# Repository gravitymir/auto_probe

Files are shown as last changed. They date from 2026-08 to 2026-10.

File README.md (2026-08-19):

# auto_probe

Отладочные core-платы на STM32 — исходники KiCad, гербера и генератор, который их собирает.

Платы не рисовались мышкой: схема, размещение, разводка и шелкография описаны Python-скриптами
поверх `pcbnew` API. Любую правку можно повторить одной командой, а результат каждый раз
прогоняется через набор проверок.

## Платы

| | STM32G474RE-CoreBoard | STM32H723ZG-CoreBoard |
|---|---|---|
| МК | STM32G474RET6, LQFP64 | STM32H723ZGT6, LQFP144 |
| Размер | 70 × 70 мм | 84 × 84 мм |
| Слоёв | 4 (GND / +3V3 внутренние) | 4 (GND / +3V3 внутренние) |
| Выводы | 4 × гребёнка 1×16, шаг 2.54 | 4 × гребёнка 2×18, шаг 2.54 |
| Питание | USB-C → AP2112K-3.3 | USB-C → AP2112K-3.3 |
| Кварцы | 8 МГц HSE + 32.768 кГц LSE | 25 МГц HSE + 32.768 кГц LSE |
| Отладка | 1×10, распиновка WeAct STLink V2.1 | 1×10, распиновка WeAct STLink V2.1 |
| Формат файлов | KiCad 7 | KiCad 10 |
| Статус | **готова к заказу** | **готова к заказу** |

Все выводы микроконтроллера выведены на гребёнки; шаг 2.54 мм — плата садится в макетку.
У H723 внутренние ряды гребёнок отстоят от центра ровно на 11 × 2.54 мм, то есть
противоположные гребёнки разнесены на 22 шага и плата ложится на сетку 0.1″.

## Что на плате (G474)

**Гребёнки.** J2 — левая, J3 — нижняя, J4 — правая, J5 — верхняя. Назначение каждого
контакта подписано на шелкографии и продублировано в [`PINOUT.csv`](boards/STM32G474RE-CoreBoard/PINOUT.csv).
На каждой гребёнке выведены GND и +3V3 — они подключены к внутренним полигонам через
thermal relief, отдельных дорожек к ним нет.

**J6 — разъём прошивки**, 1×10, распиновка один-в-один с WeAct MiniDebugger / STLink V2.1,
шлейф садится без переходников:

| 1 | 2 | 3 | 4 | 5 | 6 | 7 | 8 | 9 | 10 |
|---|---|---|---|---|---|---|---|---|---|
| 5V | GND | RX (PB6) | TX (PB7) | NRST | SWO (PB3) | GND | SWCLK | SWDIO | 3V3 |

> Контакт 1 (5V) связан с VBUS разъёма USB-C. **USB и отладчик одновременно не подключайте.**

**USB-C (J1)** — не только питание: D+/D− заведены на PA12/PA11, то есть на встроенный
USB 2.0 FS device. Через него работают USB CDC (виртуальный COM-порт) и штатный DFU-бутлоадер
STM32 — прошивка без отладчика вообще. CC1/CC2 притянуты 5.1 кОм к земле (роль устройства).

**Кнопки.** SW1 — RST, SW2 — BOOT0 (для входа в DFU: зажать BOOT, нажать RST).

**Светодиод.** D1 на PA5 (`LED_A`), через 1 кОм.

**R3 (0 Ω)** связывает +3V3 и +3V3A (VDDA / VREF+) в одной точке. Если АЦП будет шуметь —
на это же место ставится ферритовая бусина, переразводить ничего не нужно.

## Чем отличается H723

Раскладка повторяет G474: кристалл смещён к нижнему левому углу (`OFFX` / `OFFY` в
генераторе), поэтому верхнее и правое кольца шире — там и стоят светодиод, кнопки RST и
BOOT, разъём прошивки, USB-C и брендинг. USB-C стоит на плате целиком: корпус упирается
в контур, но за него не свисает.

Электрически устроена так же: те же гребёнки со всеми выводами, тот же USB-C с D+/D− на
встроенный USB FS (PA11/PA12), те же кнопки RST и BOOT0, светодиод (здесь на PB0 через
1 кОм), тот же R3 между +3V3 и +3V3A. Разъём прошивки J6 — тот же 1×10 с распиновкой
WeAct, но UART другой:

| 1 | 2 | 3 | 4 | 5 | 6 | 7 | 8 | 9 | 10 |
|---|---|---|---|---|---|---|---|---|---|
| 5V | GND | RX (PC10) | TX (PC11) | NRST | SWO (PB3) | GND | SWCLK | SWDIO | 3V3 |

Взят USART3 на PC10/PC11, а не USART1: у LQFP144 эта пара выходит на верхнюю гребёнку
рядом со SWCLK, тогда как PA9/PA10 попадают на правую гребёнку за коридором USB-C, куда
дорожку уже не проложить. Ещё из отличий: 25 МГц HSE вместо 8 МГц, две банки VCAP1/VCAP2
по 2.2 мкФ, отдельная развязка VDD33USB и 11 конденсаторов развязки под корпусом вместо 4.

HSE стоит в корпусе SMD-3225 с четырьмя падами: у JLCPCB 25 МГц в нём — Basic Part
(Yangxing X322525MOB4SI, `C9006`), тогда как двухпадовый 5032 только Extended и с
перебоями в наличии. Два лишних пада — экран корпуса, они связаны диагональю под
самим кварцем и посажены на полигон одной via. Нагрузочная ёмкость этого кварца
12 пФ, поэтому обвязка обоих генераторов — 18 пФ; кварц с другой CL ставить нельзя,
частота уйдёт.

Подписан каждый из 144 контактов, оба ряда. У J2, J3 и J5 ряды подписаны с разных сторон
гребёнки — внутренний изнутри, внешний снаружи. Напротив USB-C правое кольцо занято самим
разъёмом и его коридором, поэтому у J4 обе строки остаются слева. Подпись, которой не
хватило места, генератор сам переносит за гребёнку и сообщает об этом в отчёте сборки.
Полная карта — в [`PINOUT.csv`](boards/STM32H723ZG-CoreBoard/PINOUT.csv).

Шрифт шелкографии — 0.8 мм при толщине линии 0.15 мм: это минимум, который JLCPCB
печатает без расплывания. В кольце между гребёнкой и краем платы остаётся 3.7 мм, и
пятизначное имя таким шрифтом туда уже не входит — у нескольких цепей на шелке
короткая форма (`3V3A`, `PC2C`, `USBDP`). В цепях, схеме и `PINOUT.csv` имена полные.

Рядом с деталью печатается только обозначение: под корпусом МК банки развязки стоят
сеткой 3.2 мм, и номиналы читаемым шрифтом там просто не помещаются. Вместо этого на
обратной стороне, в свободных площадках у J4, напечатана таблица «обозначение —
номинал» на все 35 компонентов платы.

Схема H723 нарисована на листе A1: один символ LQFP144 занимает 76 × 188 мм, и вместе с
четырьмя гребёнками 2×18 и 26 конденсаторами на A2 (как у G474) он не раскладывается.

## Как открыть

Футпринты у обеих плат лежат в собственной библиотеке проекта `auto_probe.pretty` рядом с
платой и подключаются через `fp-lib-table` — системные библиотеки KiCad не нужны, и проект
не зависит от того, какая версия KiCad стоит у вас или у сборщика.

```
boards/STM32G474RE-CoreBoard/STM32G474RE-CoreBoard.kicad_pro
boards/STM32H723ZG-CoreBoard/STM32H723ZG-CoreBoard.kicad_pro
```

G474 сохранена в формате KiCad 7 (KiCad 8/9/10 открывают её и конвертируют при первом
сохранении), H723 — в формате KiCad 10: её собирали уже им. Платы независимы, так что
разные форматы никому не мешают, но KiCad 7 файл H723 не откроет.

## Как заказать

Для JLCPCB / PCBWay достаточно одного архива:

```
boards/STM32G474RE-CoreBoard/STM32G474RE-CoreBoard_gerbers.zip
boards/STM32H723ZG-CoreBoard/STM32H723ZG-CoreBoard_gerbers.zip
```

Внутри: 4 слоя меди, паяльная маска, шелкография, паста, контур платы (`.gm1`) и сверловка
(PTH / NPTH раздельно). Параметры заказа: 4 слоя, 1.6 мм, HASL или ENIG, минимальный
зазор 0.2 мм, минимальное отверстие 0.2 мм.

Для монтажа на заводе — `BOM.csv` и `pos.csv` рядом с платой. В BOM G474 проставлены
номера LCSC для микроконтроллера, стабилизатора и USB-C; у H723 — для стабилизатора и
USB-C, номер самого STM32H723ZGT6 подставьте сами. Пассивку подберите из JLCPCB Basic
Parts по номиналу и типоразмеру.

## Генератор

```
gen/
├── kigen.py        разбор библиотек символов, генерация .kicad_sch
├── pcbhelp.py      обёртка над pcbnew: размещение, дорожки, via, полигоны, текст
├── kicadenv.py     где лежат библиотеки KiCad и различия API между версиями
├── build_g474.py   сборка платы G474 целиком
├── build_h723.py   сборка платы H723
├── outputs.py      BOM.csv и PINOUT.csv из готовой платы
├── export.py       гербера, сверловка, pos.csv, PDF и архив для завода
├── drc.py          геометрический контроль зазоров + несоединённые цепи
├── conn.py         связность цепей (union-find)
├── crtyd.py        пересечения courtyard
└── silkchk.py      наложения шелкографии и печать поверх падов
```

Нужен Python с модулем `pcbnew` — от KiCad 7 или KiCad 10 (в Debian/Ubuntu — пакет
`kicad`, в Windows — `C:\Program Files\KiCad\10.0\bin\python.exe`). Каталоги системных
библиотек скрипты находят сами:

```bash
python3 gen/build_h723.py boards/STM32H723ZG-CoreBoard
python3 gen/outputs.py    boards/STM32H723ZG-CoreBoard/STM32H723ZG-CoreBoard.kicad_pcb
python3 gen/export.py     boards/STM32H723ZG-CoreBoard
python3 gen/drc.py        boards/STM32H723ZG-CoreBoard/STM32H723ZG-CoreBoard.kicad_pcb
python3 gen/silkchk.py    boards/STM32H723ZG-CoreBoard/STM32H723ZG-CoreBoard.kicad_pcb
```

`export.py` зовёт `kicad-cli`; им же гоняется штатный DRC:

```bash
kicad-cli pcb drc --schematic-parity --severity-error boards/STM32H723ZG-CoreBoard/STM32H723ZG-CoreBoard.kicad_pcb
```

Позиции надписей, выставленные вручную в KiCad, хранятся в `build_g474.py` в таблицах
`REF_AT` и `VAL_AT` — пересборка их не затирает. Остальные надписи расставляет автоподбор,
который считает занятыми чужие надписи, контуры, **пады** (шелк поверх открытой меди не
печатается) и **корпуса деталей** (иначе надпись уезжает под чип и её не видно).

## Проверки

У KiCad 7 в CLI нет DRC, поэтому проверки написаны отдельно. Текущее состояние обеих плат:

| проверка | G474 | H723 |
|---|---|---|
| зазоры меди | 0 нарушений при штатных 0.2 мм | 0 нарушений при штатных 0.2 мм |
| DRC самого KiCad | 0 ошибок | 0 ошибок |
| схема против платы | — | 0 расхождений |
| несоединённые цепи | 0 | 0 |
| пересечения courtyard | 0 | 0 |
| отверстие-отверстие | минимум 0.387 мм | минимум 0.278 мм |
| наложения шелкографии | 0 | 0 |
| шелкография поверх падов | 0 | 0 |

Обе платы проходят штатный DRC самого KiCad (проверено в KiCad 10) — 0 ошибок при netclass
clearance 0.2 мм. Сигнальные дорожки 0.15 мм, силовые 0.35 мм; минимум JLCPCB для этого
процесса — 0.09 мм. У H723 есть ещё и проверка схемы против платы (`--schematic-parity`),
её умеет только CLI KiCad 10.

Веер из 144 выводов на четыре гребёнки 2×18 упирается не в ширину дорожки, а в угол:
крайние дорожки идут под 42°, и поперёк соседа от шага 0.5 мм остаётся 0.5·cos42° = 0.37 мм.
Отсюда и вынос гребёнок на 27.94 мм от центра — на 26 мм веер в зазор 0.2 мм не укладывался
ни при какой разумной ширине.

## Что осталось

- На D+/D− нет защиты от статики (например, USBLC6-2SC6) — для прототипа терпимо.
- D+/D− заодно выведены на J4 контакты 3 и 4. Удобно для отладки, но это отвод на
  дифференциальной паре: если USB начнёт капризничать при определении — снимите с них всё.
- VBUS не заведён на вывод МК, определить подключение кабеля программно нельзя.

## Лицензия

MIT — см. [LICENSE](LICENSE).

Референсные материалы ST (схемы Nucleo MB1367 / MB1364, их гербера и BOM) в репозиторий
не включены: они распространяются по ST Open Platform License Agreement. Разбор того, что
из них полезно и как это открыть в KiCad, — в [docs/](docs/).

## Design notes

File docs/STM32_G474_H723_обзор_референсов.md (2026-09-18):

# Прототипы отладочных плат STM32G474RET6 (LQFP64) и STM32H723ZGT6 (LQFP144)

Обзор готовых открытых проектов + план собственных плат.
Дата: 16 августа 2026.

---

## 1. Короткий вывод

**Готового open-source «core board» ровно под ваши корпуса — нет.**

- Под **G474 в LQFP64** открытых KiCad-исходников не существует; все народные платы сделаны на **LQFP48/QFN48** (G474CEU6/CBT6).
- Под **H723 в LQFP144** народных плат тоже нет; WeAct сделал **LQFP100** (H723VGT6). LQFP144 встречается только в коммерческих платах (FANKE FK723M1) и в чужих больших проектах.

Зато есть два очень сильных «якоря», которые снимают 80 % работы:

1. **Официальные файлы ST на Nucleo** — там ровно ваши кристаллы в ровно ваших корпусах, и ST выкладывает не только схему PDF, но и **исходный проект платы (Altium) + производственные файлы (гербера) + BOM**.
2. **KiCad уже содержит символы и футпринты** `STM32G474RETx`, `STM32H723ZGTx`, `LQFP-64_10x10mm_P0.5mm`, `LQFP-144_20x20mm_P0.5mm` — рисовать компоненты не надо (проверено на KiCad 7, в 8/9 то же самое).

---

## 2. Что нашлось: STM32G474

| Проект | Корпус / MCU | Что отдают | Лицензия | Ценность |
|---|---|---|---|---|
| **ST NUCLEO-G474RE (MB1367)** | **LQFP64, G474RET6** — точное попадание | Схема PDF (ревизии C04/C05/D01), `mb1367_bdp.zip` — **исходный проект платы**, `mb1367_manufacturing.zip` — **гербера**, `mb1367_bom.zip` | ST (для референса) | ★★★★★ Эталон питания, кварцев, BOOT0, NRST, SWD |
| **ST B-G474E-DPOW1 (MB1428)** | LQFP64, G474RE | Схема + UM2577 + BDP | ST | ★★★★ Второй независимый референс обвязки |
| **nikolai2111/STM32G474_Black-Pill_v3.0** | UFQFPN48, G474CEU6 | **Полный исходник KiCad 8** (.kicad_sch/.kicad_pcb), гербера, панель, BOM (xlsx+pdf), 3D, PCB-Fab | **CERN-OHL-P-2.0** (разрешительная, можно брать в закрытый проект) | ★★★★★ Единственный полноценный KiCad-исходник. Готовая обвязка: USB-C, LDO AP7343, BAT54, QSPI-флеш W25Q32, кнопки BOOT/RESET |
| **WeActStudio.STM32G474CoreBoard** | QFN48 и LQFP48 | Только схема PDF + STEP + чертёж контура | не указана | ★★★ Ориентир по формфактору «квадратный core board» |

**Что берём:** схемотехнику обвязки — из Black Pill v3.0 (готовые KiCad-цепи, копируются мышкой); распиновку/питание LQFP64 — из MB1367.

---

## 3. Что нашлось: STM32H723

| Проект | Корпус / MCU | Что отдают | Лицензия | Ценность |
|---|---|---|---|---|
| **ST NUCLEO-H723ZG (MB1364)** | **LQFP144, H723ZGT6** — точное попадание | Схема PDF, `mb1364_bdp.zip` (**исходник платы**), `mb1364_manufacturing.zip` (**гербера**), `mb1364-bom.zip` | ST | ★★★★★ Эталон: развязка 11×VDD, VCAP, VDD33USB, PDR_ON, стек слоёв |
| **FANKE FK723M1-ZGT6** | **LQFP144, H723ZGT6** | Схема PDF; поддержан «из коробки» в Zephyr | коммерческая | ★★★★ Это буквально ваш формфактор: 2 × гребёнка 30×2 + SWD 4×2, USB-C, QSPI-флеш, microSD, FPC под LCD/камеру. Дешевле купить как reference, чем повторять |
| **WeActStudio.MiniSTM32H723** | LQFP100, H723VGT6 | Схема PDF, STEP, Altium IntLib, чертёж контура 40.64 × 66.88 мм | не указана | ★★★ Хороший минимальный H7 core board, но не 144 |
| **BoltzRnD/SmartPrintCoreH7x** | LQFP144 (H743ZIT, в BOM альтернатива H723ZGT) | **Полный KiCad-проект** + гербера + BOM | **GPL-3.0** ⚠️ вирусная | ★★★ Живой KiCad-пример LQFP144 STM32H7. Смотреть можно, копировать в закрытый проект — нельзя |

⚠️ H743ZIT и H723ZGT в LQFP144 **пин-совместимы по питанию и большинству портов**, но не идентичны — сверять по даташиту обязательно.

---

## 4. Ключевые факты по обвязке (проверено по символам KiCad + даташитам)

### STM32G474RET6, LQFP64
- Питание: **VDD ×4** (16, 32, 48, 64), **VSS ×4** (15, 31, 47, 63), VBAT (1), VDDA (29), VSSA (27), VREF+ (28).
- **VCAP нет** — у STM32G4 внутренний регулятор без внешних банок. Это сильно упрощает плату.
- **NRST = PG10, вывод 7** (по умолчанию работает как сброс).
- **BOOT0 = PB8, вывод 61.**
- HSE: PF0/PF1 (5, 6). LSE: PC14/PC15 (3, 4).
- SWD: PA13 = SWDIO (49), PA14 = SWCLK (50).
- USB FS: PA11/PA12 (45, 46), без внешнего PHY.
- Развязка: 4 × 100 нФ + 1 × 4.7 мкФ, VDDA — 100 нФ + 1 мкФ, VREF+ — 100 нФ + 1 мкФ.
- **Хватает 2 слоёв**, но 4 слоя на JLCPCB стоят копейки и дают сплошную землю — берём 4.

### STM32H723ZGT6, LQFP144
- Питание: **VDD ×11** (17, 30, 39, 52, 62, 72, 84, 108, 121, 131, 144), **VSS ×9**, VBAT (6), VDDA (33), VSSA (31), VREF+ (32), **VDD33USB (95)**.
- **VCAP ×2 — выводы 71 и 106.** Обязательно по 2.2 мкФ керамики X7R максимально близко к выводам.
- **PDR_ON — вывод 143.** Для простой платы притянуть к VDD.
- **NRST — 25**, **BOOT0 — 138.**
- В LQFP144 у H723 **выводов SMPS нет** — питание только через внутренний LDO. Это хорошая новость: никаких катушек, схема питания как у F4.
- Развязка: по 100 нФ на каждый VDD (11 шт.) + 2 × 4.7 мкФ + 10 мкФ на входе.
- **Минимум 4 слоя** (SIG / GND / PWR / SIG). Ядро на 550 МГц с плохой землёй работать не будет.

---

## 5. Предлагаемый формфактор

Вы выбрали два варианта — они не конфликтуют, делаются одной серией:

### Плата A — «G474 core board», квадрат
- LQFP64 (10 × 10 мм) в центре, гребёнки 2.54 по всем четырём сторонам.
- **~50 × 50 мм**, 4 слоя. 64 вывода = 4 × 16 контактов по краям — идеально ложится на квадрат.
- Реально влезает и в **DIP-стиль**: две гребёнки 1 × 32 с шагом 2.54 → плата 25.4 × 81 мм (ширина 1000 mil, ставится в макетку с зазором в один ряд).
- Обвязка: USB-C (только питание + USB FS), LDO 3.3 В, кнопки RESET/BOOT0, светодиод, HSE 8/24 МГц, LSE 32.768 кГц, SWD 4-пин 1.27 или 2.54.

### Плата B — «H723 core board», квадрат
- LQFP144 (20 × 20 мм) в центре. 144 вывода на 2.54 по периметру одним рядом дало бы плату ~110 мм — много.
- Поэтому: **две гребёнки 30 × 2 по бокам** (как у FK723M1) → плата **~55 × 65 мм**, 4 слоя.
- DIP-вариант для LQFP144 практически нереален — там ширина упрётся в 20 мм корпус + два ряда.
- Обвязка: USB-C, LDO 3.3 В (≥500 мА), VCAP-банки, PDR_ON, HSE 25 МГц, LSE 32.768 кГц, SWD, RESET/BOOT0, опционально QSPI-флеш.

---

## 6. Ссылки для скачивания (прямые)

**STM32G474 / Nucleo-G474RE (MB1367)**
- Схема: `https://www.st.com/resource/en/schematic_pack/mb1367-g474re-d01-schematic.pdf`
- Исходный проект платы: `https://www.st.com/resource/en/board_manufacturing_specification/mb1367_bdp.zip`
- Гербера: `https://www.st.com/resource/en/board_manufacturing_specification/mb1367_manufacturing.zip`
- BOM: `https://www.st.com/resource/en/bill_of_materials/mb1367_bom.zip`

**STM32H723 / Nucleo-H723ZG (MB1364)**
- Схема: `https://www.st.com/resource/en/schematic_pack/mb1364-h723zg-e01_schematic.pdf`
- Исходный проект платы: `https://www.st.com/resource/en/board_manufacturing_specification/mb1364_bdp.zip`
- Гербера: `https://www.st.com/resource/en/board_manufacturing_specification/mb1364_manufacturing.zip`
- BOM: `https://www.st.com/resource/en/bill_of_materials/mb1364-bom.zip`

**Открытые репозитории**
- `https://github.com/nikolai2111/STM32G474_Black-Pill_v3.0` — KiCad 8, CERN-OHL-P
- `https://github.com/WeActStudio/WeActStudio.STM32G474CoreBoard`
- `https://github.com/WeActStudio/WeActStudio.MiniSTM32H723`
- `https://github.com/BoltzRnD/SmartPrintCoreH7x` — KiCad, GPL-3.0

**Полезные AN от ST**
- AN5093 — Getting started with STM32G4
- AN2867 — Oscillator design guide
- AN4938 / AN5312 — STM32H7 hardware design & power supply
- AN2606 — System memory boot mode

## 7. Заказ на JLCPCB (2026-09-09)

Заказ **W2026090920369332**: плата H723 со сборкой, 5 шт.
- PCB Prototype `Y4-12849203A` — гербер `STM32H723ZG-CoreBoard_gerbers_Y4`, $7.00
- Standard PCBA `SMT026090864246` — по BOM.csv/pos.csv, $161.91

Итоговая стоимость заказа — **$239.33**
(платы и компоненты $168.91, доставка $25.66, пошлины и налоги $44.76), оплата картой без комиссии.

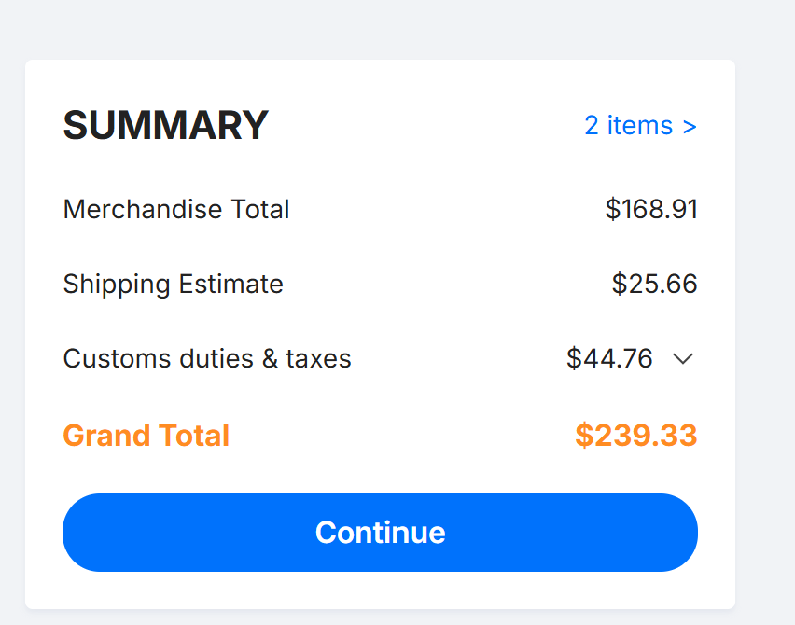
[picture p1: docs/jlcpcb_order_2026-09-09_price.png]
Стоимость заказа JLCPCB, итог $239.33


Доплата от 2026-09-18: услуга **Depanel boards & edge rail before delivery** — **$3.31**
(первое 96-часовое окно оплаты истекло, услугу отменяли, но поддержка JLCPCB реактивировала кнопку оплаты).
Полная стоимость заказа с доплатой — **$242.64**.

Разъёмы (гребёнки) в SMT-монтаж не входят, заказаны отдельно на AliExpress 2026-09-14, ~€75.30 вместе
с зарядным устройством: 2x18 female 35 шт (порты H723), 1x16 stackable 30 шт (порты G474),
1x10 stackable 20 шт (DEBUG обеих плат).

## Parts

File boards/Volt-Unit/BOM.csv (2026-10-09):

Comment | Designator | Footprint | LCSC Part # | Qty | Note
100nF | C2,C3 | auto_probe:C_0402_1005Metric | C1525 | 2 | проверить наличие на складе
470pF | C1 | auto_probe:C_0402_1005Metric | C75274 | 1 | проверить наличие на складе
PROBE | J2 | auto_probe:PinHeader_1x02_P2.54mm_Vertical |  | 1 | выводная: в SMT-монтаж не идёт, паяется отдельно
LOGIC | J1 | auto_probe:PinHeader_1x03_P2.54mm_Vertical |  | 1 | выводная: в SMT-монтаж не идёт, паяется отдельно
220R | R7 | auto_probe:R_0402_1005Metric | C25091 | 1 | проверить наличие на складе
10k | R5,R6 | auto_probe:R_0402_1005Metric | C25744 | 2 | проверить наличие на складе
18k | R3,R4 | auto_probe:R_0402_1005Metric | C25762 | 2 | проверить наличие на складе
470k | R1,R2 | auto_probe:R_0805_2012Metric | C17709 | 2 | проверить наличие на складе
LMV358 | U1 | auto_probe:SOIC-8_3.9x4.9mm_P1.27mm | C7980 | 1 | проверить наличие на складе
BAT54S | D1,D2 | auto_probe:SOT-23 | C47546 | 2 | проверить наличие на складе

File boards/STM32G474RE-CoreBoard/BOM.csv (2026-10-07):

Comment | Designator | Footprint | LCSC Part # | Qty | Note
100nF | C1,C17,C2,C3,C4,C9 | auto_probe:C_0402_1005Metric | C1525 | 6 | проверить наличие на складе
18pF | C15,C16 | auto_probe:C_0402_1005Metric | C1549 | 2 | проверить наличие на складе
33pF | C13,C14 | auto_probe:C_0402_1005Metric | C1562 | 2 | проверить наличие на складе
100nF | C6 | auto_probe:C_0603_1608Metric | C14663 | 1 | проверить наличие на складе
1uF | C10 | auto_probe:C_0603_1608Metric | C15849 | 1 | проверить наличие на складе
10uF | C7,C8 | auto_probe:C_0805_2012Metric | C15850 | 2 | проверить наличие на складе
4.7uF | C5 | auto_probe:C_0805_2012Metric | C1779 | 1 | проверить наличие на складе
8MHz | Y1 | auto_probe:Crystal_SMD_5032-2Pin_5.0x3.2mm | C115962 | 1 | проверить наличие на складе; обвязка 33 пФ - только под CL 20 пФ
32.768kHz | Y2 | auto_probe:Crystal_SMD_MicroCrystal_CC7V-T1A-2Pin_3.2x1.5mm | C97606 | 1 | проверить наличие на складе; обвязка 18 пФ - только под CL 12...12.5 пФ
LED | D1 | auto_probe:LED_0805_2012Metric | C84256 | 1 | проверить наличие на складе
STM32G474RET6 | U1 | auto_probe:LQFP-64_10x10mm_P0.5mm | C521608 | 1 | проверить наличие на складе
DEBUG | J6 | auto_probe:PinHeader_1x10_P2.54mm_Vertical |  | 1 | выводная: в SMT-монтаж не идёт, паяется отдельно
PORT_B | J3 | auto_probe:PinHeader_1x16_P2.54mm_Vertical |  | 1 | выводная: в SMT-монтаж не идёт, паяется отдельно
PORT_L | J2 | auto_probe:PinHeader_1x16_P2.54mm_Vertical |  | 1 | выводная: в SMT-монтаж не идёт, паяется отдельно
PORT_R | J4 | auto_probe:PinHeader_1x16_P2.54mm_Vertical |  | 1 | выводная: в SMT-монтаж не идёт, паяется отдельно
PORT_T | J5 | auto_probe:PinHeader_1x16_P2.54mm_Vertical |  | 1 | выводная: в SMT-монтаж не идёт, паяется отдельно
1k | R5 | auto_probe:R_0402_1005Metric | C11702 | 1 | проверить наличие на складе
0R/FB | R3 | auto_probe:R_0402_1005Metric | C17168 | 1 | проверить наличие на складе
10k | R4 | auto_probe:R_0402_1005Metric | C25744 | 1 | проверить наличие на складе
5.1k | R1,R2 | auto_probe:R_0402_1005Metric | C25905 | 2 | проверить наличие на складе
AP2112K-3.3 | U2 | auto_probe:SOT-23-5 | C51118 | 1 | проверить наличие на складе; аналог по выводам ME6211C33M5G-N (C82942), SOT-23-5, 1 VIN / 2 GND / 3 EN / 5 VOUT
BOOT0/RESET | SW1,SW2 | auto_probe:SW_SPST_SKQG_WithoutStem | C318884 | 2 | проверить наличие на складе
USB-C | J1 | auto_probe:USB_C_Receptacle_HRO_TYPE-C-31-M-12 | C165948 | 1 | проверить наличие на складе

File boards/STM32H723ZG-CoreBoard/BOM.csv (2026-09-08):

Comment | Designator | Footprint | LCSC Part # | Qty | Note
100nF | C1,C10,C11,C2,C3,C4,C5,C6,C7,C70,C74,C77,C8,C9 | auto_probe:C_0402_1005Metric | C1525 | 14 | проверить наличие на складе
18pF | C60,C61,C62,C63 | auto_probe:C_0402_1005Metric | C1549 | 4 | проверить наличие на складе
100nF | C52 | auto_probe:C_0603_1608Metric | C14663 | 1 | проверить наличие на складе
1uF | C71 | auto_probe:C_0603_1608Metric | C15849 | 1 | проверить наличие на складе
2.2uF | C72,C73 | auto_probe:C_0603_1608Metric | C23630 | 2 | проверить наличие на складе
10uF | C50,C51 | auto_probe:C_0805_2012Metric | C15850 | 2 | проверить наличие на складе
4.7uF | C75,C76 | auto_probe:C_0805_2012Metric | C1779 | 2 | проверить наличие на складе
25MHz | Y1 | auto_probe:Crystal_SMD_3225-4Pin_3.2x2.5mm | C9006 | 1 | проверить наличие на складе; обвязка 18 пФ - только под CL 12...12.5 пФ
32.768kHz | Y2 | auto_probe:Crystal_SMD_MicroCrystal_CC7V-T1A-2Pin_3.2x1.5mm | C97606 | 1 | проверить наличие на складе; обвязка 18 пФ - только под CL 12...12.5 пФ
LED | D1 | auto_probe:LED_0805_2012Metric | C84256 | 1 | проверить наличие на складе
STM32H723ZGT6 | U1 | auto_probe:LQFP-144_20x20mm_P0.5mm | C730146 | 1 | проверить наличие на складе
DEBUG | J6 | auto_probe:PinHeader_1x10_P2.54mm_Vertical |  | 1 | выводная: в SMT-монтаж не идёт, паяется отдельно
PORT_B | J3 | auto_probe:PinHeader_2x18_P2.54mm_Vertical |  | 1 | выводная: в SMT-монтаж не идёт, паяется отдельно
PORT_L | J2 | auto_probe:PinHeader_2x18_P2.54mm_Vertical |  | 1 | выводная: в SMT-монтаж не идёт, паяется отдельно
PORT_R | J4 | auto_probe:PinHeader_2x18_P2.54mm_Vertical |  | 1 | выводная: в SMT-монтаж не идёт, паяется отдельно
PORT_T | J5 | auto_probe:PinHeader_2x18_P2.54mm_Vertical |  | 1 | выводная: в SMT-монтаж не идёт, паяется отдельно
1k | R5 | auto_probe:R_0402_1005Metric | C11702 | 1 | проверить наличие на складе
0R/FB | R3 | auto_probe:R_0402_1005Metric | C17168 | 1 | проверить наличие на складе
10k | R4 | auto_probe:R_0402_1005Metric | C25744 | 1 | проверить наличие на складе
5.1k | R1,R2 | auto_probe:R_0402_1005Metric | C25905 | 2 | проверить наличие на складе
AP2112K-3.3 | U2 | auto_probe:SOT-23-5 | C51118 | 1 | проверить наличие на складе; аналог по выводам ME6211C33M5G-N (C82942), SOT-23-5, 1 VIN / 2 GND / 3 EN / 5 VOUT
BOOT0/RESET | SW1,SW2 | auto_probe:SW_SPST_SKQG_WithoutStem | C318884 | 2 | проверить наличие на складе
USB-C | J1 | auto_probe:USB_C_Receptacle_HRO_TYPE-C-31-M-12 | C165948 | 1 | проверить наличие на складе

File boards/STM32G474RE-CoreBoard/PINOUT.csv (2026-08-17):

Header | HeaderPin | MCU_Pin | Signal
J2 | 1 | 1 | +3V3
J2 | 2 | 2 | PC13
J2 | 3 | 3 | LSE_IN
J2 | 4 | 4 | LSE_OUT
J2 | 5 | 5 | HSE_IN
J2 | 6 | 6 | HSE_OUT
J2 | 7 | 7 | NRST
J2 | 8 | 8 | PC0
J2 | 9 | 9 | PC1
J2 | 10 | 10 | PC2
J2 | 11 | 11 | PC3
J2 | 12 | 12 | PA0
J2 | 13 | 13 | PA1
J2 | 14 | 14 | PA2
J2 | 15 | 15 | GND
J2 | 16 | 16 | +3V3
J3 | 1 | 17 | PA3
J3 | 2 | 18 | PA4
J3 | 3 | 19 | LED_A
J3 | 4 | 20 | PA6
J3 | 5 | 21 | PA7
J3 | 6 | 22 | PC4
J3 | 7 | 23 | PC5
J3 | 8 | 24 | PB0
J3 | 9 | 25 | PB1
J3 | 10 | 26 | PB2
J3 | 11 | 27 | GND
J3 | 12 | 28 | +3V3A
J3 | 13 | 29 | +3V3A
J3 | 14 | 30 | PB10
J3 | 15 | 31 | GND
J3 | 16 | 32 | +3V3
J4 | 1 | 48 | +3V3
J4 | 2 | 47 | GND
J4 | 3 | 46 | USB_DP
J4 | 4 | 45 | USB_DM
J4 | 5 | 44 | PA10
J4 | 6 | 43 | PA9
J4 | 7 | 42 | PA8
J4 | 8 | 41 | PC9
J4 | 9 | 40 | PC8
J4 | 10 | 39 | PC7
J4 | 11 | 38 | PC6
J4 | 12 | 37 | PB15
J4 | 13 | 36 | PB14
J4 | 14 | 35 | PB13
J4 | 15 | 34 | PB12
J4 | 16 | 33 | PB11
J5 | 1 | 64 | +3V3
J5 | 2 | 63 | GND
J5 | 3 | 62 | PB9
J5 | 4 | 61 | BOOT0
J5 | 5 | 60 | PB7
J5 | 6 | 59 | PB6
J5 | 7 | 58 | PB5
J5 | 8 | 57 | PB4
J5 | 9 | 56 | SWO
J5 | 10 | 55 | PD2
J5 | 11 | 54 | PC12
J5 | 12 | 53 | PC11
J5 | 13 | 52 | PC10
J5 | 14 | 51 | PA15
J5 | 15 | 50 | SWCLK
J5 | 16 | 49 | SWDIO

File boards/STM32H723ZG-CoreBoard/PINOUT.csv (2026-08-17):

Header | HeaderPin | MCU_Pin | Signal
J2 | 1 | 2 | PE3
J2 | 2 | 1 | PE2
J2 | 3 | 4 | PE5
J2 | 4 | 3 | PE4
J2 | 5 | 6 | +3V3
J2 | 6 | 5 | PE6
J2 | 7 | 8 | LSE_IN
J2 | 8 | 7 | PC13
J2 | 9 | 10 | PF0
J2 | 10 | 9 | LSE_OUT
J2 | 11 | 12 | PF2
J2 | 12 | 11 | PF1
J2 | 13 | 14 | PF4
J2 | 14 | 13 | PF3
J2 | 15 | 16 | GND
J2 | 16 | 15 | PF5
J2 | 17 | 18 | PF6
J2 | 18 | 17 | +3V3
J2 | 19 | 20 | PF8
J2 | 20 | 19 | PF7
J2 | 21 | 22 | PF10
J2 | 22 | 21 | PF9
J2 | 23 | 24 | HSE_OUT
J2 | 24 | 23 | HSE_IN
J2 | 25 | 26 | PC0
J2 | 26 | 25 | NRST
J2 | 27 | 28 | PC2_C
J2 | 28 | 27 | PC1
J2 | 29 | 30 | +3V3
J2 | 30 | 29 | PC3_C
J2 | 31 | 32 | +3V3A
J2 | 32 | 31 | GND
J2 | 33 | 34 | PA0
J2 | 34 | 33 | +3V3A
J2 | 35 | 36 | PA2
J2 | 36 | 35 | PA1
J3 | 1 | 38 | GND
J3 | 2 | 37 | PA3
J3 | 3 | 40 | PA4
J3 | 4 | 39 | +3V3
J3 | 5 | 42 | PA6
J3 | 6 | 41 | PA5
J3 | 7 | 44 | PC4
J3 | 8 | 43 | PA7
J3 | 9 | 46 | LED_A
J3 | 10 | 45 | PC5
J3 | 11 | 48 | PB2
J3 | 12 | 47 | PB1
J3 | 13 | 50 | PF12
J3 | 14 | 49 | PF11
J3 | 15 | 52 | +3V3
J3 | 16 | 51 | GND
J3 | 17 | 54 | PF14
J3 | 18 | 53 | PF13
J3 | 19 | 56 | PG0
J3 | 20 | 55 | PF15
J3 | 21 | 58 | PE7
J3 | 22 | 57 | PG1
J3 | 23 | 60 | PE9
J3 | 24 | 59 | PE8
J3 | 25 | 62 | +3V3
J3 | 26 | 61 | GND
J3 | 27 | 64 | PE11
J3 | 28 | 63 | PE10
J3 | 29 | 66 | PE13
J3 | 30 | 65 | PE12
J3 | 31 | 68 | PE15
J3 | 32 | 67 | PE14
J3 | 33 | 70 | PB11
J3 | 34 | 69 | PB10
J3 | 35 | 72 | +3V3
J3 | 36 | 71 | VCAP1
J4 | 1 | 108 | +3V3
J4 | 2 | 107 | GND
J4 | 3 | 106 | VCAP2
J4 | 4 | 105 | SWDIO
J4 | 5 | 104 | USB_DP
J4 | 6 | 103 | USB_DM
J4 | 7 | 102 | PA10
J4 | 8 | 101 | PA9
J4 | 9 | 100 | PA8
J4 | 10 | 99 | PC9
J4 | 11 | 98 | PC8
J4 | 12 | 97 | PC7
J4 | 13 | 96 | PC6
J4 | 14 | 95 | +3V3
J4 | 15 | 94 | GND
J4 | 16 | 93 | PG8
J4 | 17 | 92 | PG7
J4 | 18 | 91 | PG6
J4 | 19 | 90 | PG5
J4 | 20 | 89 | PG4
J4 | 21 | 88 | PG3
J4 | 22 | 87 | PG2
J4 | 23 | 86 | PD15
J4 | 24 | 85 | PD14
J4 | 25 | 84 | +3V3
J4 | 26 | 83 | GND
J4 | 27 | 82 | PD13
J4 | 28 | 81 | PD12
J4 | 29 | 80 | PD11
J4 | 30 | 79 | PD10
J4 | 31 | 78 | PD9
J4 | 32 | 77 | PD8
J4 | 33 | 76 | PB15
J4 | 34 | 75 | PB14
J4 | 35 | 74 | PB13
J4 | 36 | 73 | PB12
J5 | 1 | 144 | +3V3
J5 | 2 | 143 | +3V3
J5 | 3 | 142 | PE1
J5 | 4 | 141 | PE0
J5 | 5 | 140 | PB9
J5 | 6 | 139 | PB8
J5 | 7 | 138 | BOOT0
J5 | 8 | 137 | PB7
J5 | 9 | 136 | PB6
J5 | 10 | 135 | PB5
J5 | 11 | 134 | PB4
J5 | 12 | 133 | PB3
J5 | 13 | 132 | PG15
J5 | 14 | 131 | +3V3
J5 | 15 | 130 | GND
J5 | 16 | 129 | PG14
J5 | 17 | 128 | PG13
J5 | 18 | 127 | PG12
J5 | 19 | 126 | PG11
J5 | 20 | 125 | PG10
J5 | 21 | 124 | PG9
J5 | 22 | 123 | PD7
J5 | 23 | 122 | PD6
J5 | 24 | 121 | +3V3
J5 | 25 | 120 | GND
J5 | 26 | 119 | PD5
J5 | 27 | 118 | PD4
J5 | 28 | 117 | PD3
J5 | 29 | 116 | PD2
J5 | 30 | 115 | PD1
J5 | 31 | 114 | PD0
J5 | 32 | 113 | PC12
J5 | 33 | 112 | PC11
J5 | 34 | 111 | PC10
J5 | 35 | 110 | PA15
J5 | 36 | 109 | SWCLK

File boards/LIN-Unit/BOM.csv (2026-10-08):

Comment | Designator | Footprint | LCSC Part # | Qty | Note
100nF | C1,C2 | auto_probe:C_0402_1005Metric | C1525 | 2 | проверить наличие на складе
1uF | C3 | auto_probe:C_0603_1608Metric | C15849 | 1 | проверить наличие на складе
SMAJ24CA | D2 | auto_probe:D_SMA | C28092 | 1 | проверить наличие на складе
1N4148W | D1 | auto_probe:D_SOD-123 | C81598 | 1 | проверить наличие на складе
PESD1LIN | D3,D4 | auto_probe:D_SOD-323 | C58901 | 2 | проверить наличие на складе
BUS | J3 | auto_probe:PinHeader_1x04_P2.54mm_Vertical |  | 1 | выводная: в SMT-монтаж не идёт, паяется отдельно
LOGIC | J2 | auto_probe:PinHeader_1x06_P2.54mm_Vertical |  | 1 | выводная: в SMT-монтаж не идёт, паяется отдельно
10k | R3,R4 | auto_probe:R_0402_1005Metric | C25744 | 2 | проверить наличие на складе
510R | R1,R2 | auto_probe:R_0805_2012Metric | C17734 | 2 | проверить наличие на складе
TLE7258D | U1,U2 | auto_probe:VSON-8-1EP_3x3mm_P0.65mm_EP1.6x2.4mm | C540017 | 2 | проверить наличие на складе

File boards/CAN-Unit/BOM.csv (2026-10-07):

Comment | Designator | Footprint | LCSC Part # | Qty | Note
100nF | C1 | auto_probe:C_0402_1005Metric | C1525 | 1 | проверить наличие на складе
1uF | C2 | auto_probe:C_0603_1608Metric | C15849 | 1 | проверить наличие на складе
CAN | J3 | auto_probe:PinHeader_1x02_P2.54mm_Vertical |  | 1 | выводная: в SMT-монтаж не идёт, паяется отдельно
LOGIC | J2 | auto_probe:PinHeader_1x02_P2.54mm_Vertical |  | 1 | выводная: в SMT-монтаж не идёт, паяется отдельно
PWR | J1 | auto_probe:PinHeader_1x02_P2.54mm_Vertical |  | 1 | выводная: в SMT-монтаж не идёт, паяется отдельно
120R | R1 | auto_probe:R_0603_1608Metric | C22787 | 1 | проверить наличие на складе
TCAN332G | U1 | auto_probe:SOT-23-8 | C2671083 | 1 | проверить наличие на складе

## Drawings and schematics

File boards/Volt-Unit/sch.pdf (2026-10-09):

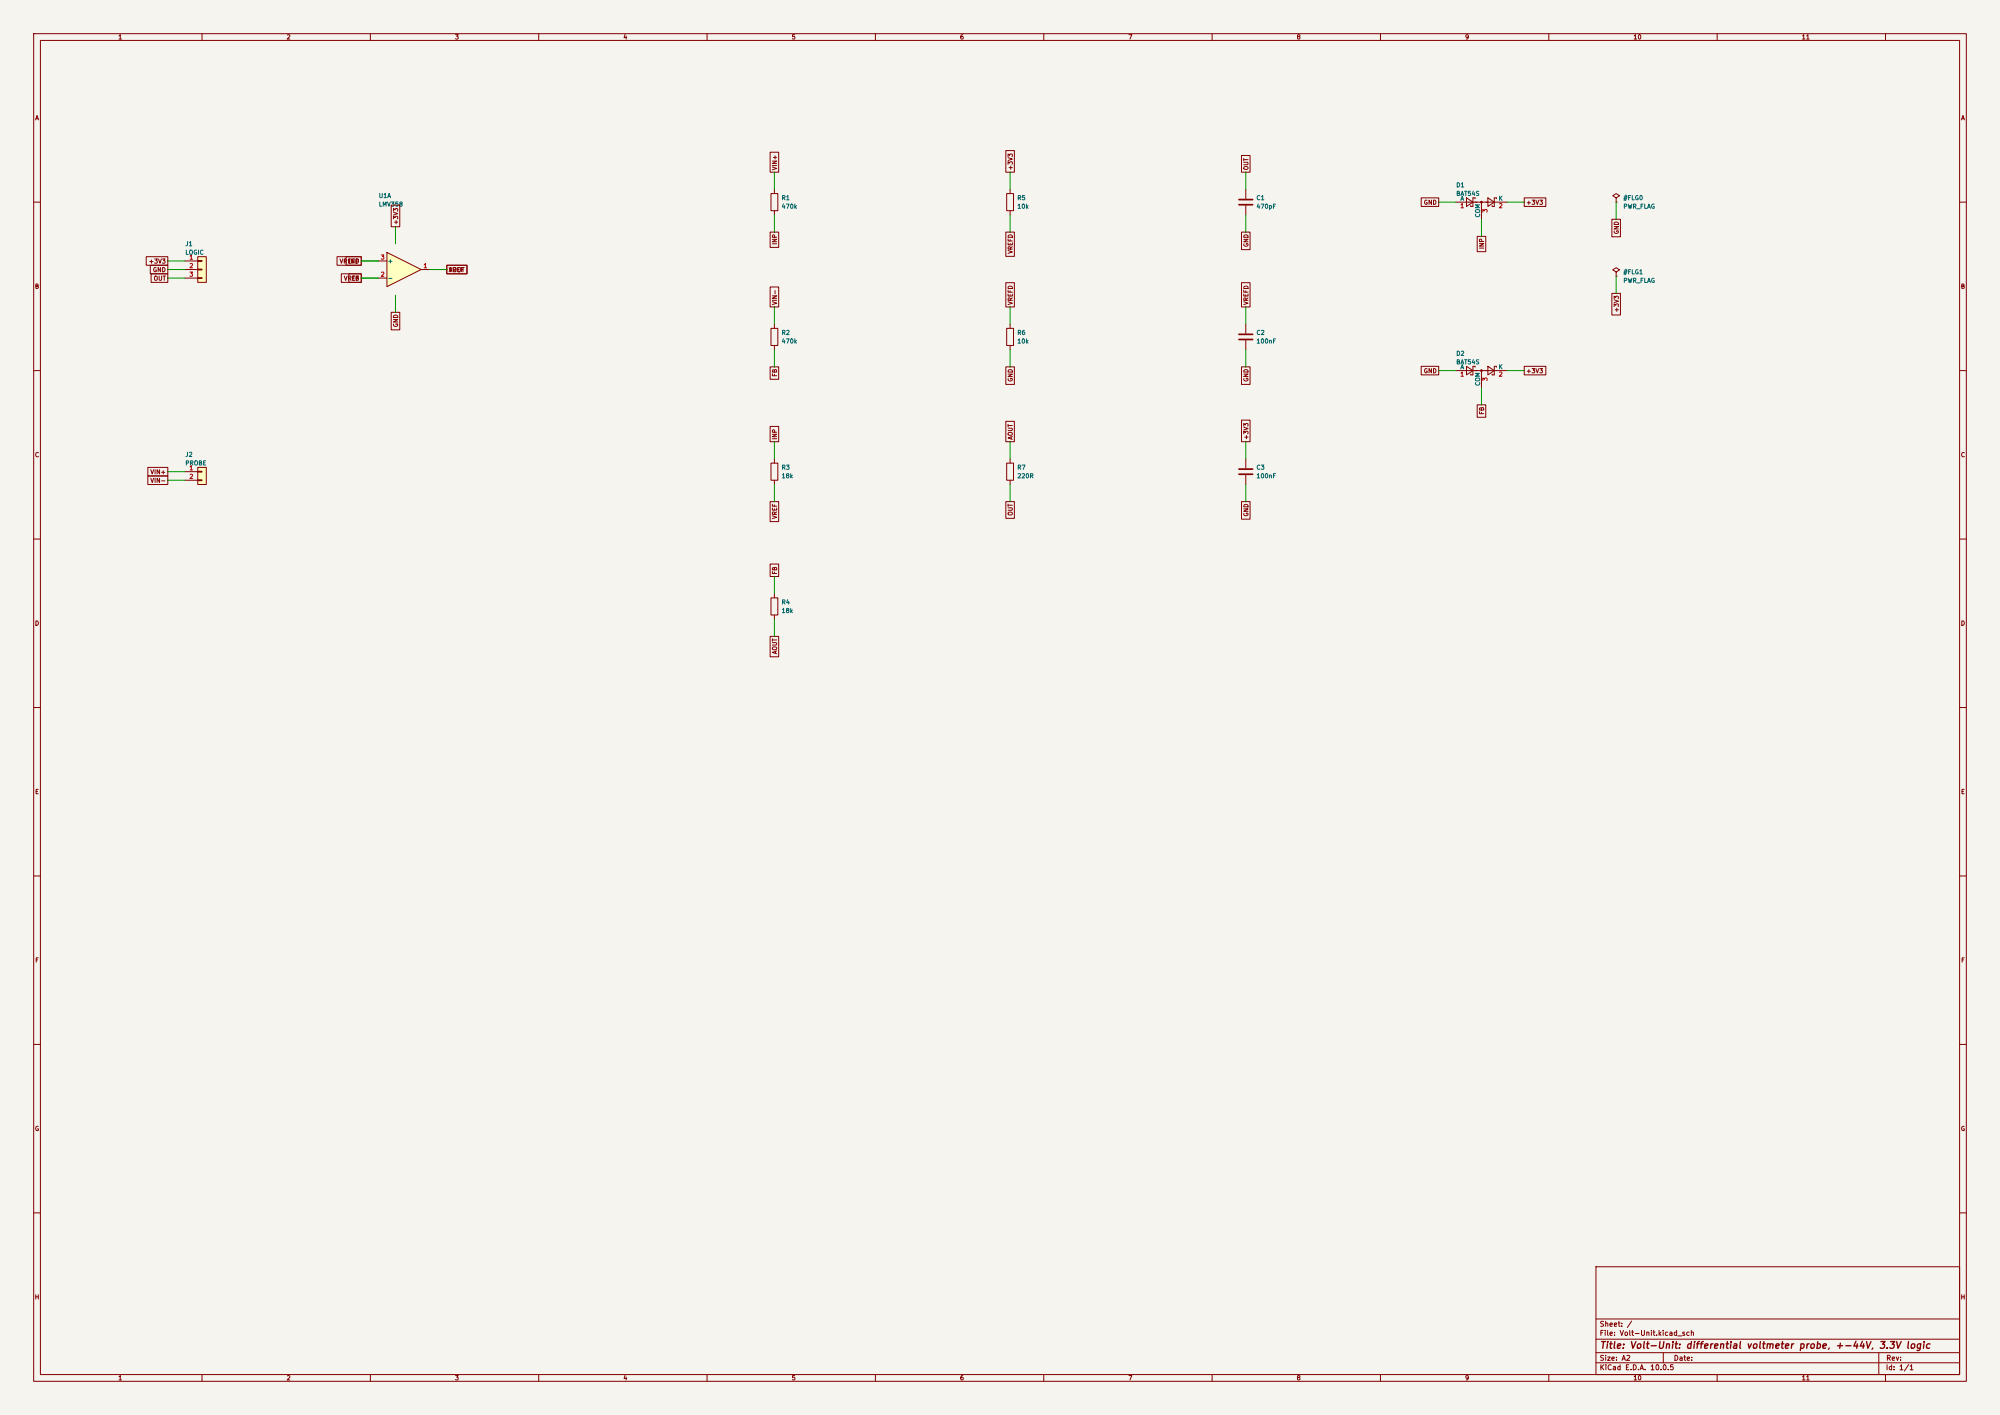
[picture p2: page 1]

#FLG1 PWR_FLAG +3V3 +3V3 VREFD VREFD GND VREF FB AOUT

Sheet: /
File: Volt-Unit.kicad_sch
Title: Volt-Unit: differential voltmeter probe, +-44V, 3.3V logic

Size: A2 | Rev:
KiCad E.D.A. 10.0.5 | Id: 1/1

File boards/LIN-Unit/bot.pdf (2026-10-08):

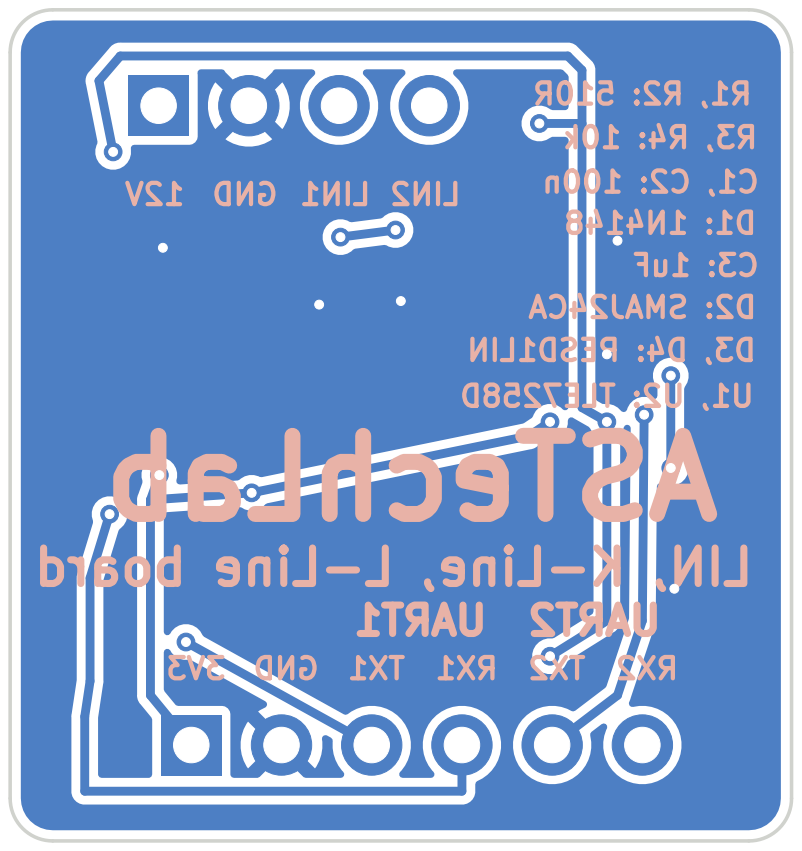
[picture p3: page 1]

100n C2: C1, 10k R4: R3, 1N4148 D1: 1uF C3: UART1 UART2 board L-Line K-Line, LIN, ASTechLab

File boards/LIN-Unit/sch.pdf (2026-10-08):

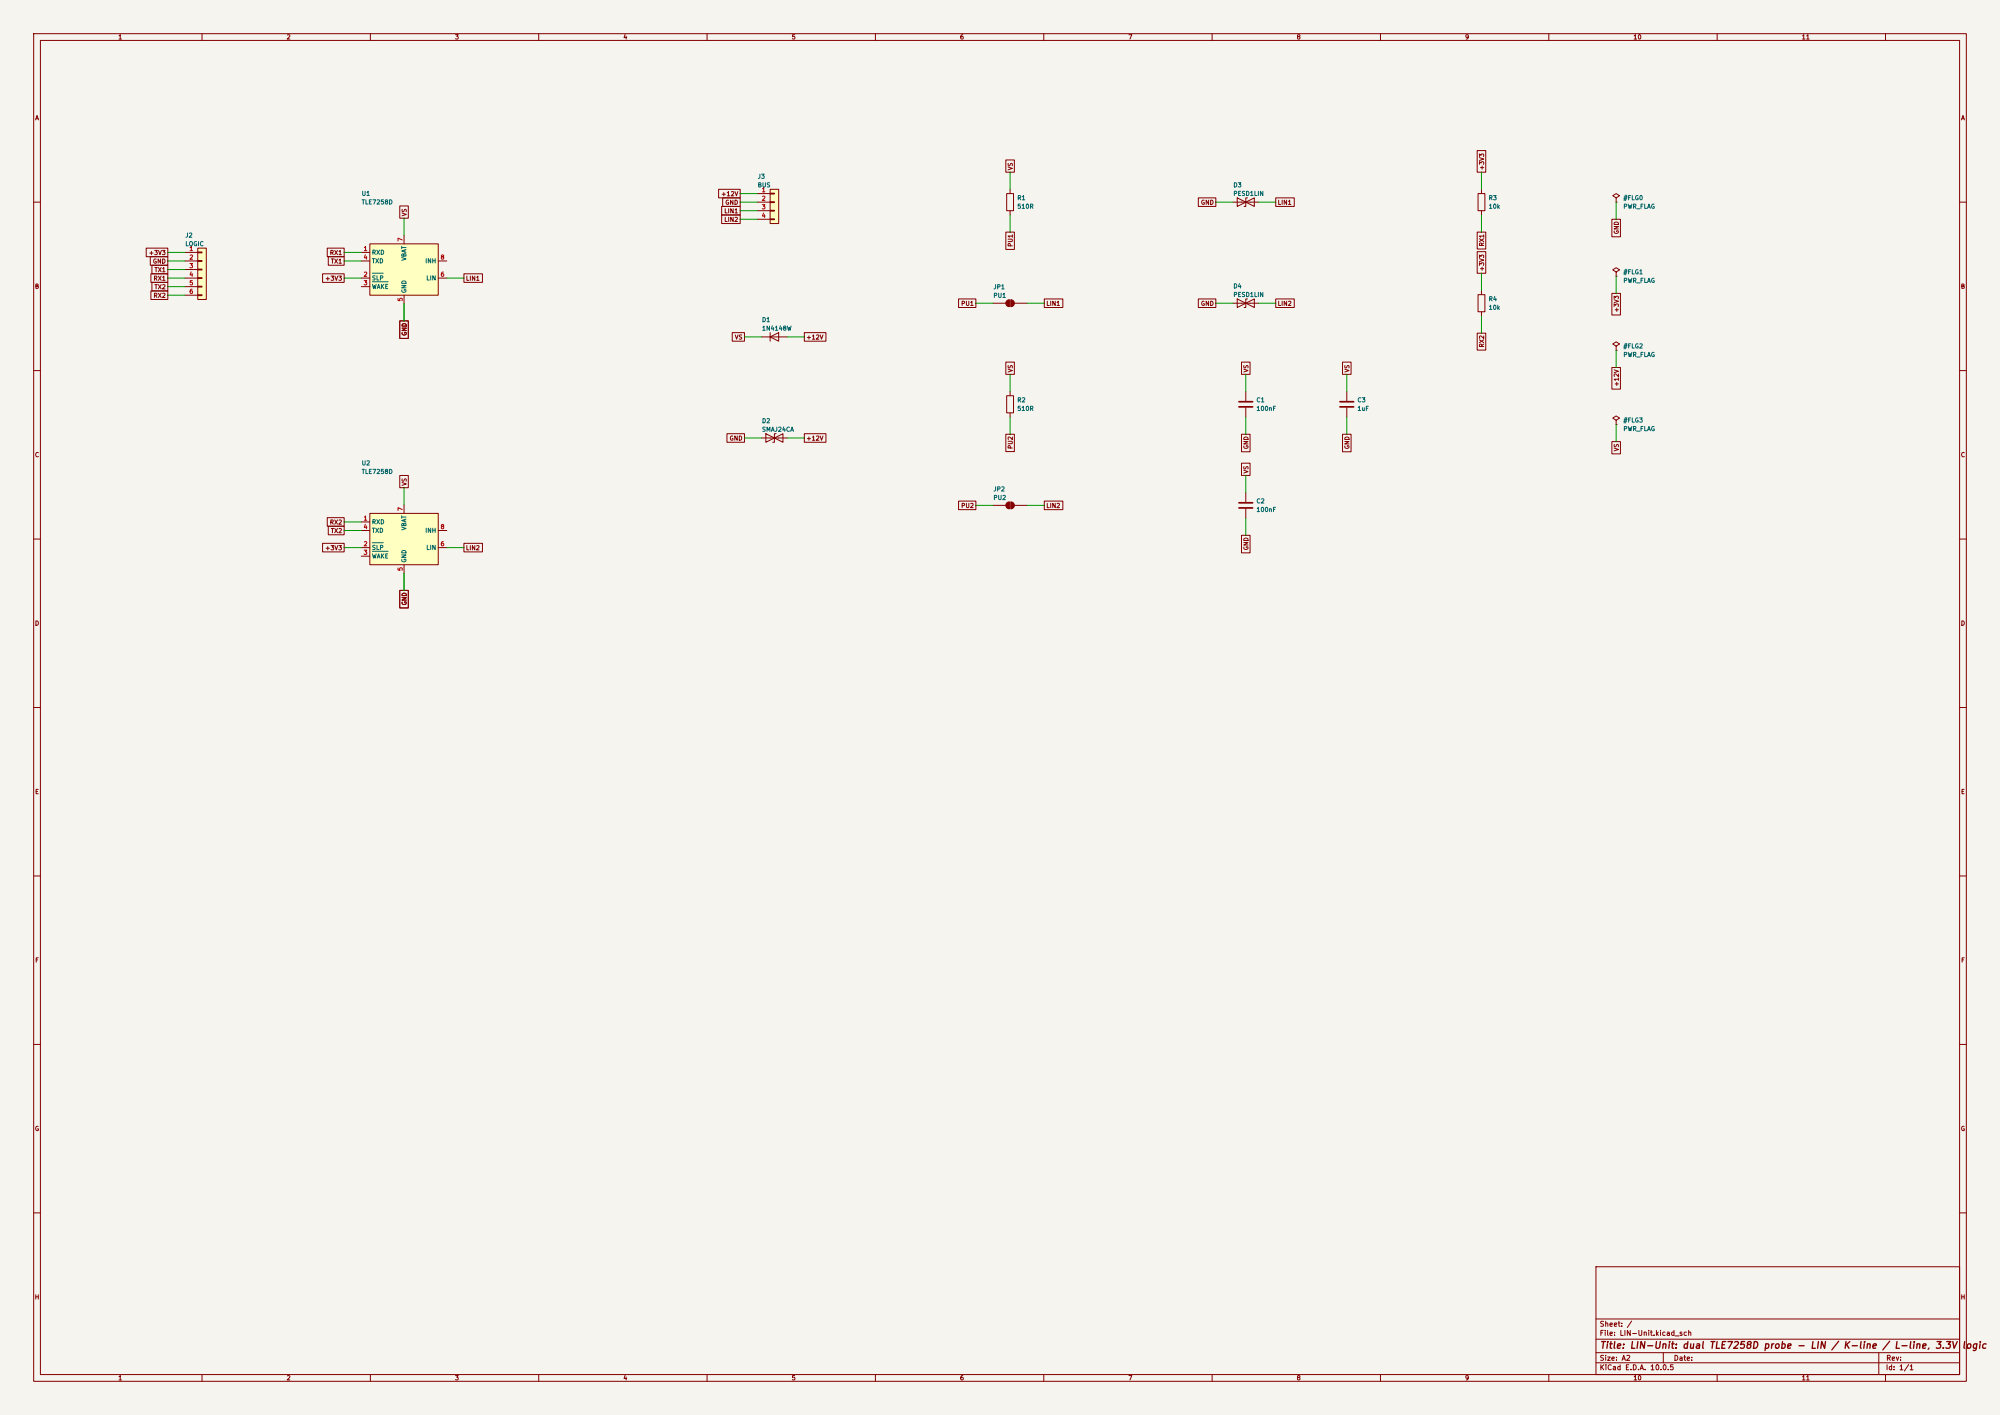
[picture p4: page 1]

Sheet: /
File: LIN-Unit.kicad_sch
Title: LIN-Unit: dual TLE7258D probe - LIN / K-line / L-line, 3.3V logic

Size: A2 | Rev:
KiCad E.D.A. 10.0.5 | Id: 1/1

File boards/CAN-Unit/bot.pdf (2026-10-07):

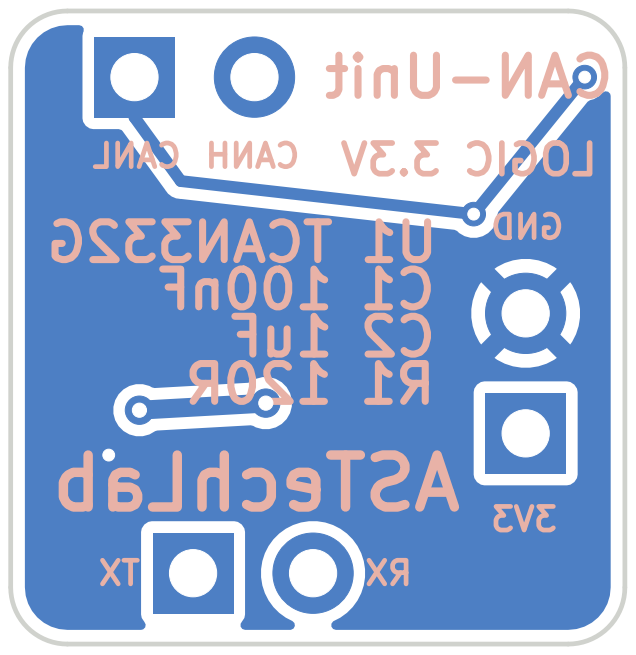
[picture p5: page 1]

3V3 GND 3.3V LOGIC TCAN332G U1 100nF C1 1uF C2 120R R1 CAN-Unit ASTechLab

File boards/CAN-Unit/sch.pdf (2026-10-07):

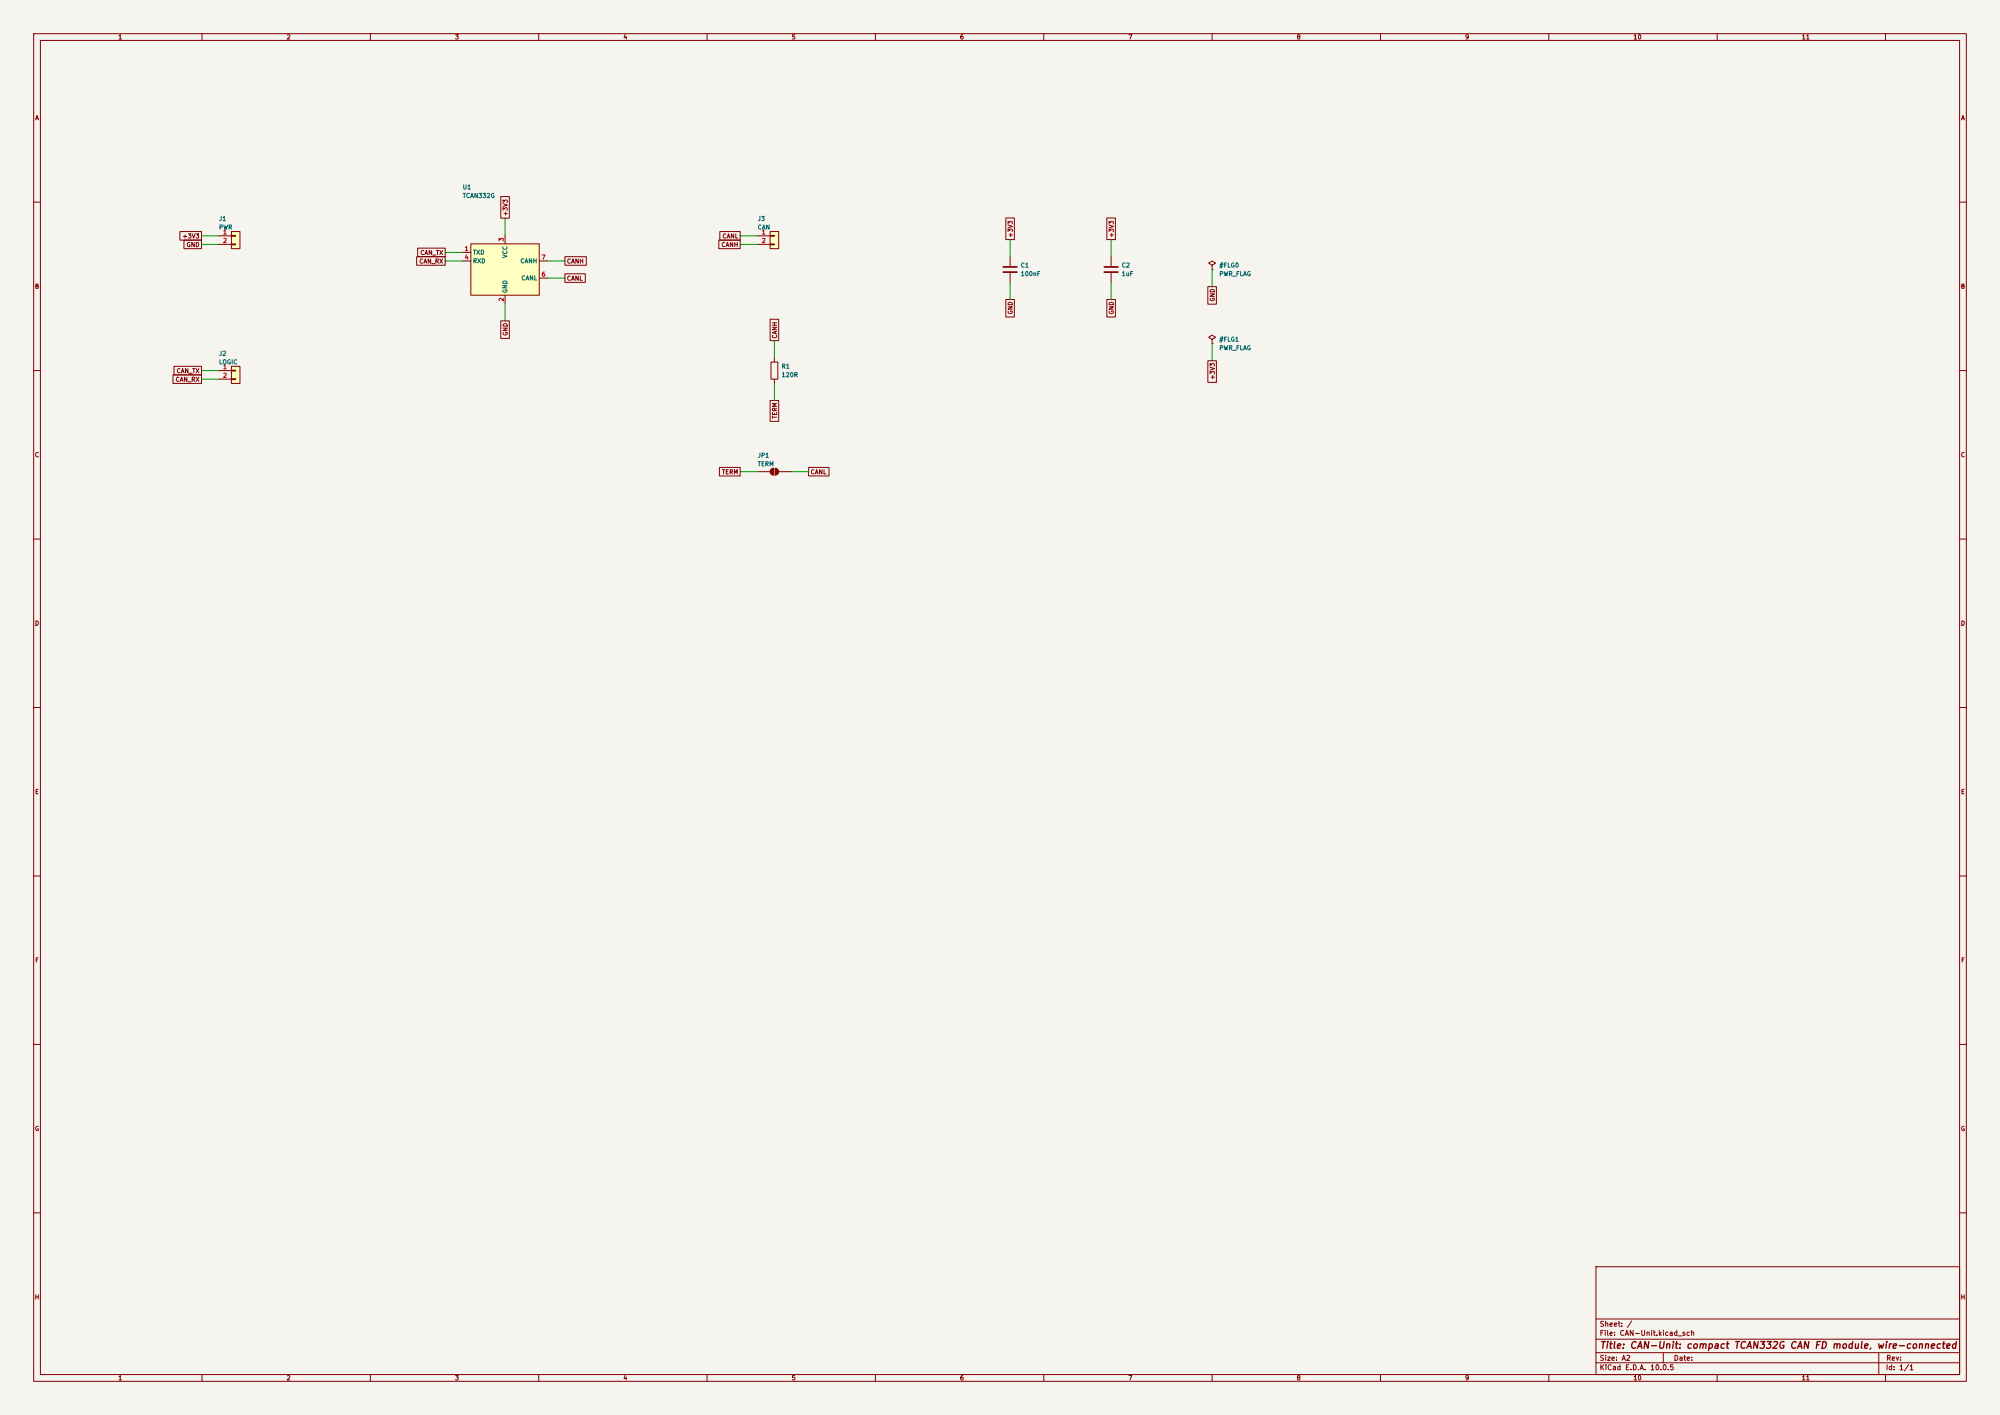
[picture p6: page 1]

Sheet: /
File: CAN-Unit.kicad_sch
Title: CAN-Unit: compact TCAN332G CAN FD module, wire-connected

Size: A2 | Rev:
KiCad E.D.A. 10.0.5 | Id: 1/1

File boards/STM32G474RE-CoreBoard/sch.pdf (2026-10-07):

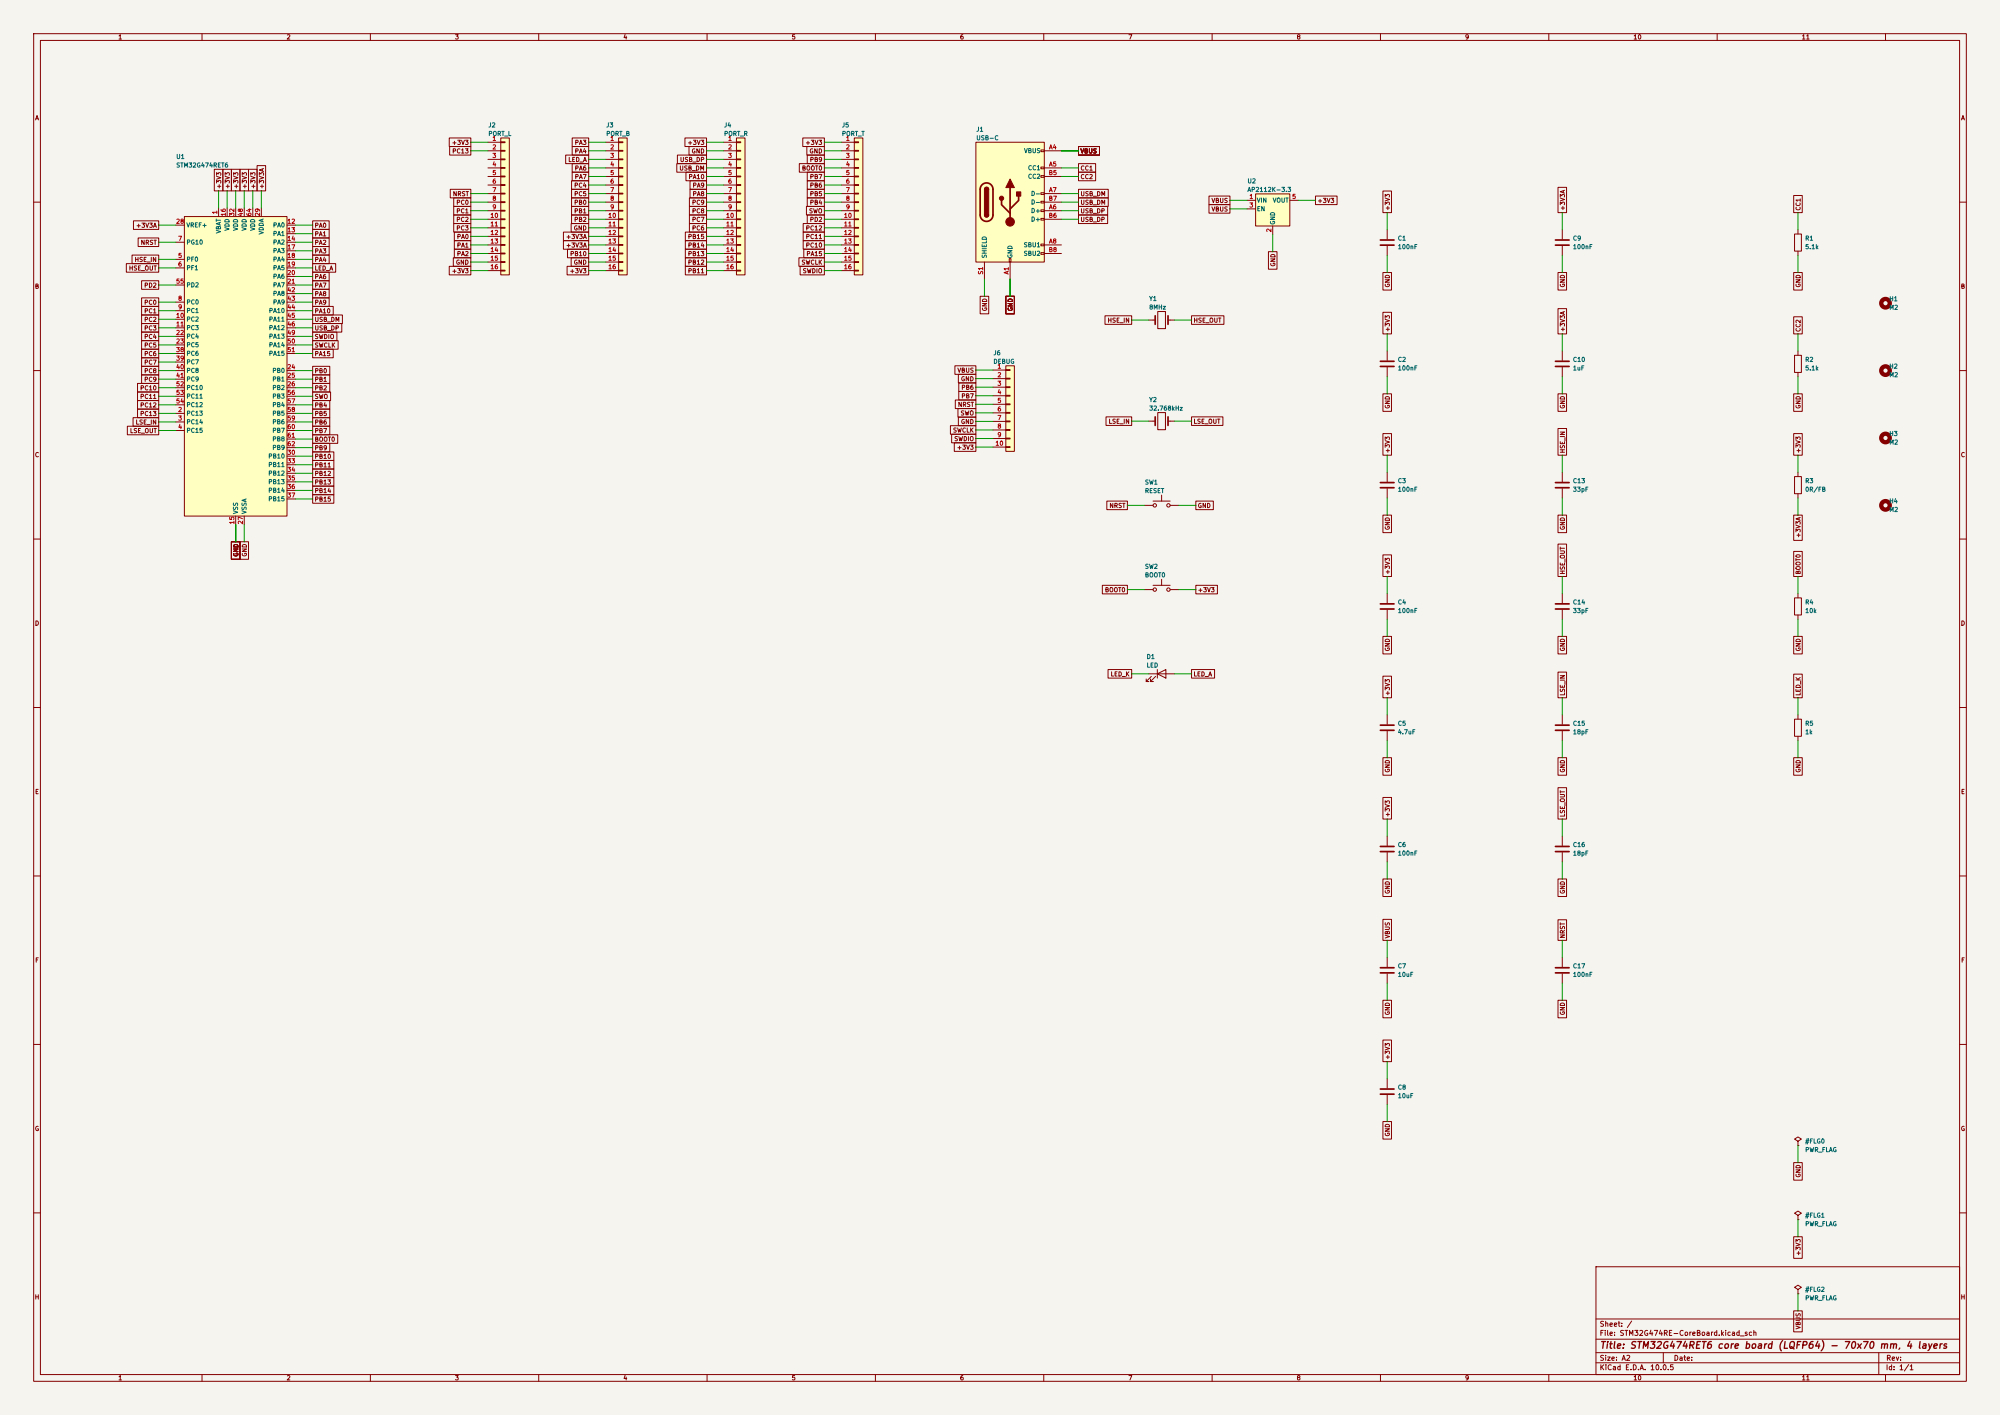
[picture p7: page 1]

Sheet: /
File: STM32G474RE-CoreBoard.kicad_sch
Title: STM32G474RET6 core board (LQFP64) - 70x70 mm, 4 layers

Size: A2 | Rev:
KiCad E.D.A. 10.0.5 | Id: 1/1

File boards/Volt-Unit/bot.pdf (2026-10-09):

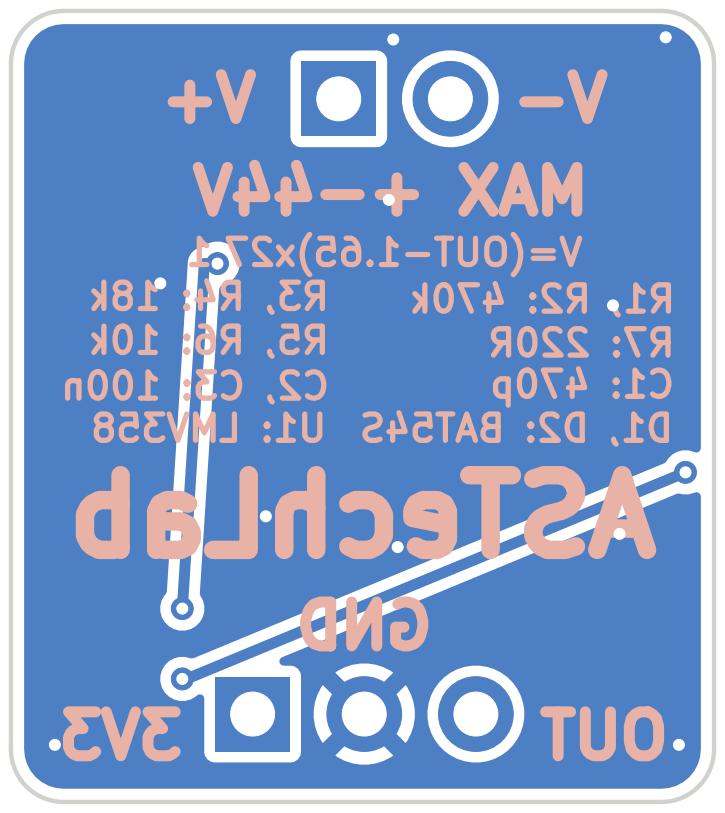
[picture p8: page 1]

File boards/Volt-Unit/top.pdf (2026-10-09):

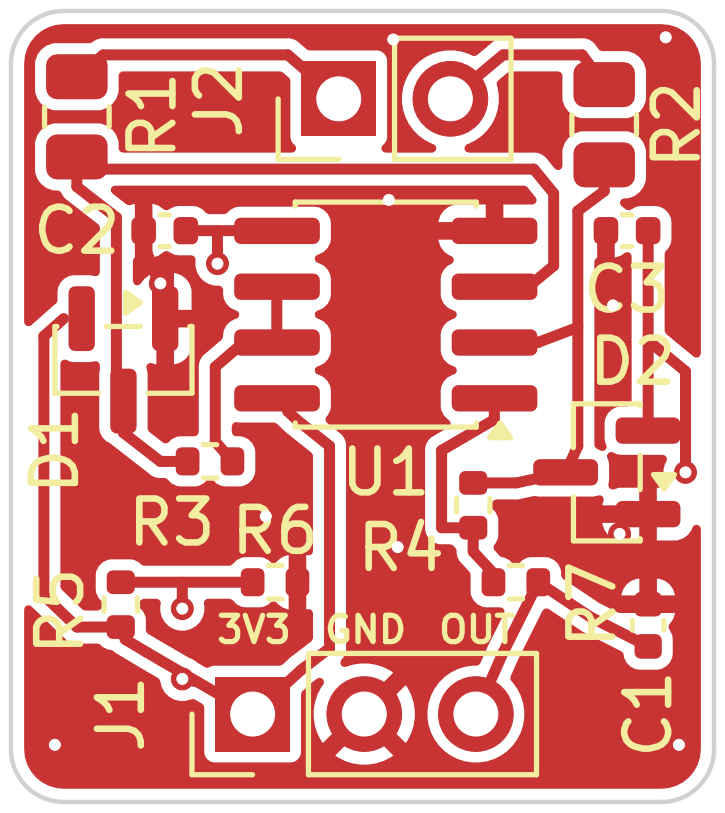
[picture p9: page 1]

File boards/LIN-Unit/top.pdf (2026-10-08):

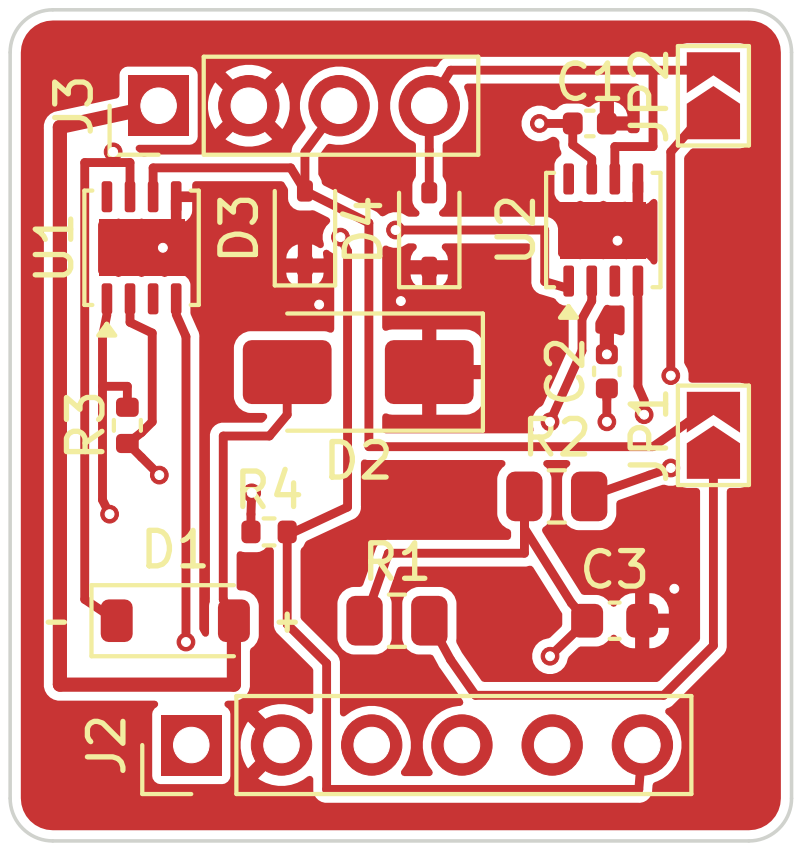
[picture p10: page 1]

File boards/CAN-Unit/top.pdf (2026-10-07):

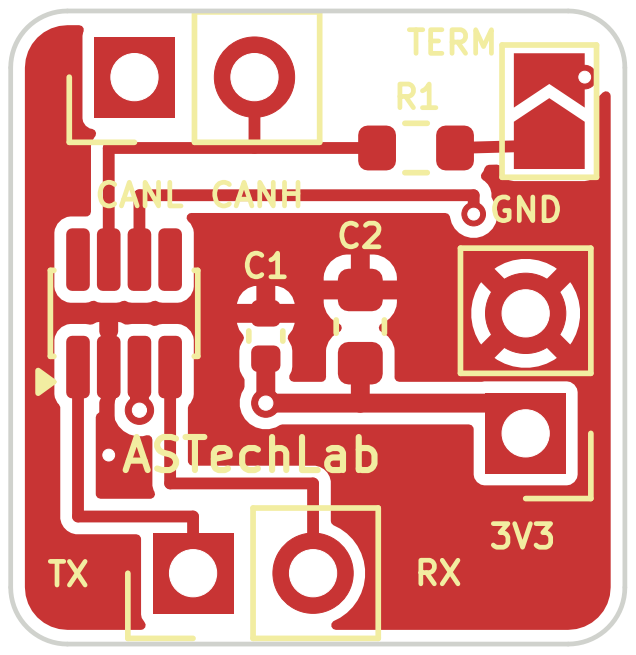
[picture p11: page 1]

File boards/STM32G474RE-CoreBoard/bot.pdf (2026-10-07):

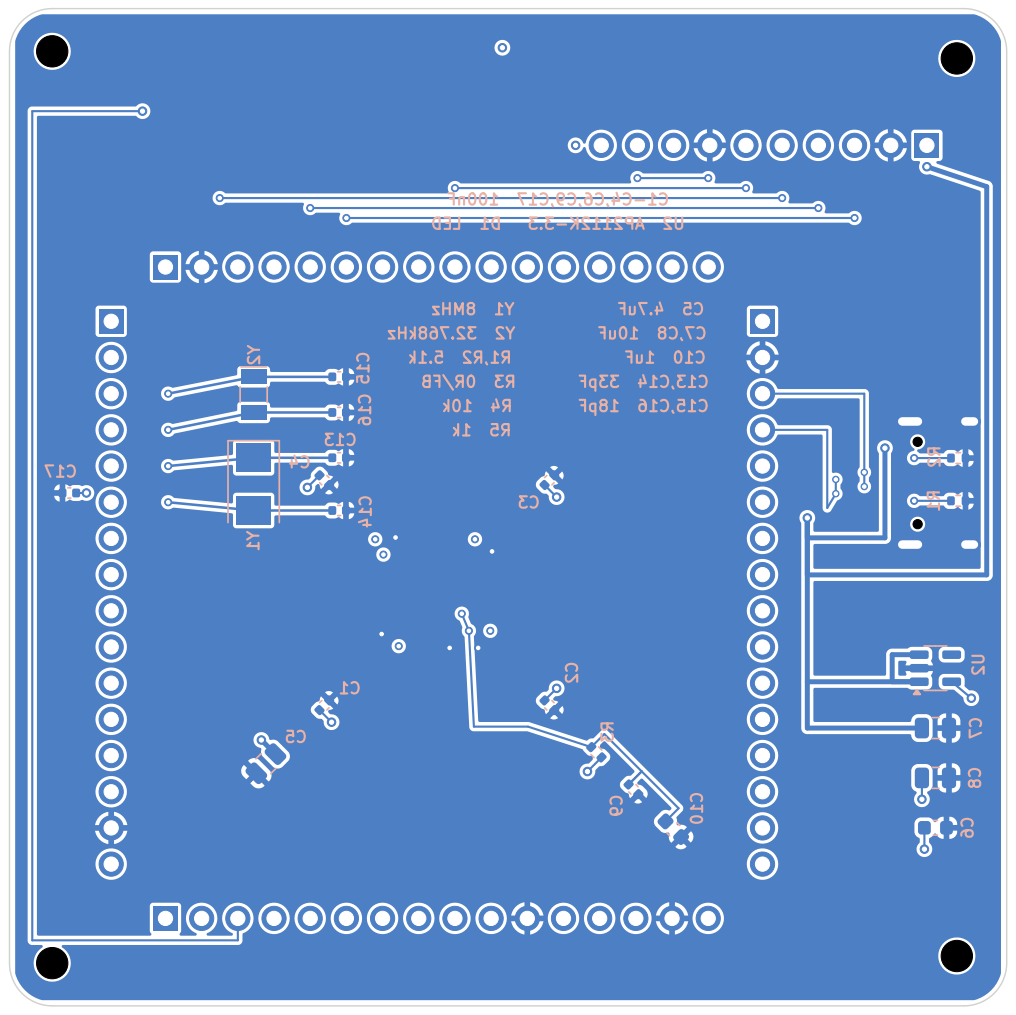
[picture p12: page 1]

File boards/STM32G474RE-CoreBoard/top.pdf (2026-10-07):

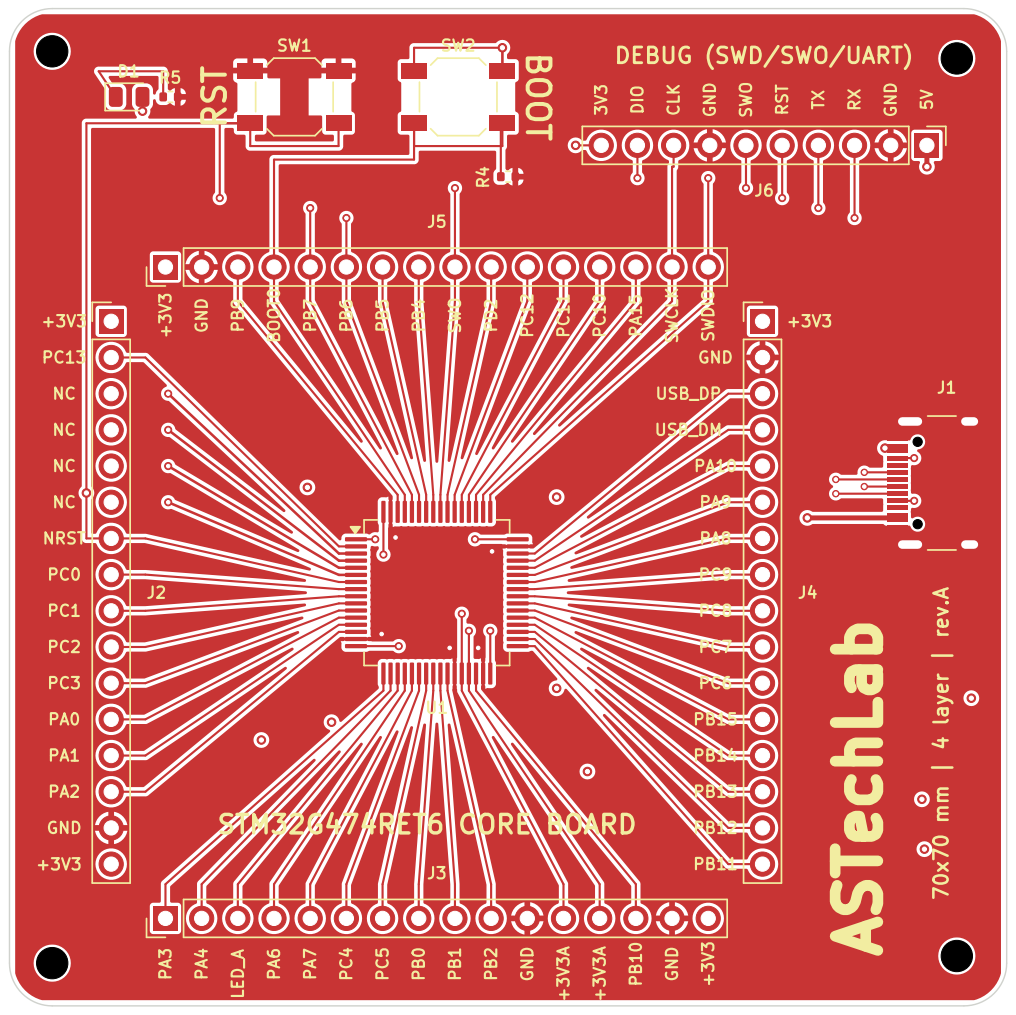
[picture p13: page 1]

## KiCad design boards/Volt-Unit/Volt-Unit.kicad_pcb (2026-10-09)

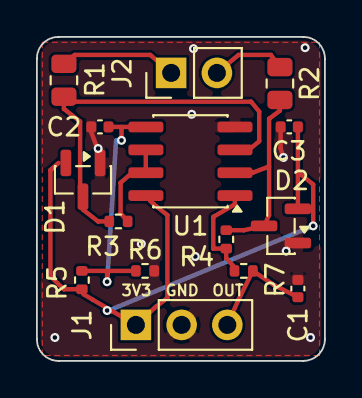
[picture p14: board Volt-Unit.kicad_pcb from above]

Board: 2 copper layers, 16.0 x 18.0 mm, 15 parts (0 on the bottom side), 10 nets.

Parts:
C1: 470pF; C_0402_1005Metric
C2, C3: 100nF; C_0402_1005Metric
D1, D2: BAT54S; SOT-23
J1: LOGIC; PinHeader_1x03_P2.54mm_Vertical
J2: PROBE; PinHeader_1x02_P2.54mm_Vertical
R1, R2: 470k; R_0805_2012Metric
R3, R4: 18k; R_0402_1005Metric
R5, R6: 10k; R_0402_1005Metric
R7: 220R; R_0402_1005Metric
U1: LMV358; SOIC-8_3.9x4.9mm_P1.27mm

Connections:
+3V3: C3.1, D1.2, D2.2, J1.1, R5.1, U1.8
AOUT: R4.2, R7.1, U1.1
FB: D2.3, R2.2, R4.1, U1.2
GND: C1.2, C2.2, C3.2, D1.1, D2.1, J1.2, R6.2, U1.4
INP: D1.3, R1.2, R3.1, U1.3
OUT: C1.1, J1.3, R7.2
VIN+: J2.1, R1.1
VIN-: J2.2, R2.1
VREF: R3.2, U1.6, U1.7
VREFD: C2.1, R5.2, R6.1, U1.5

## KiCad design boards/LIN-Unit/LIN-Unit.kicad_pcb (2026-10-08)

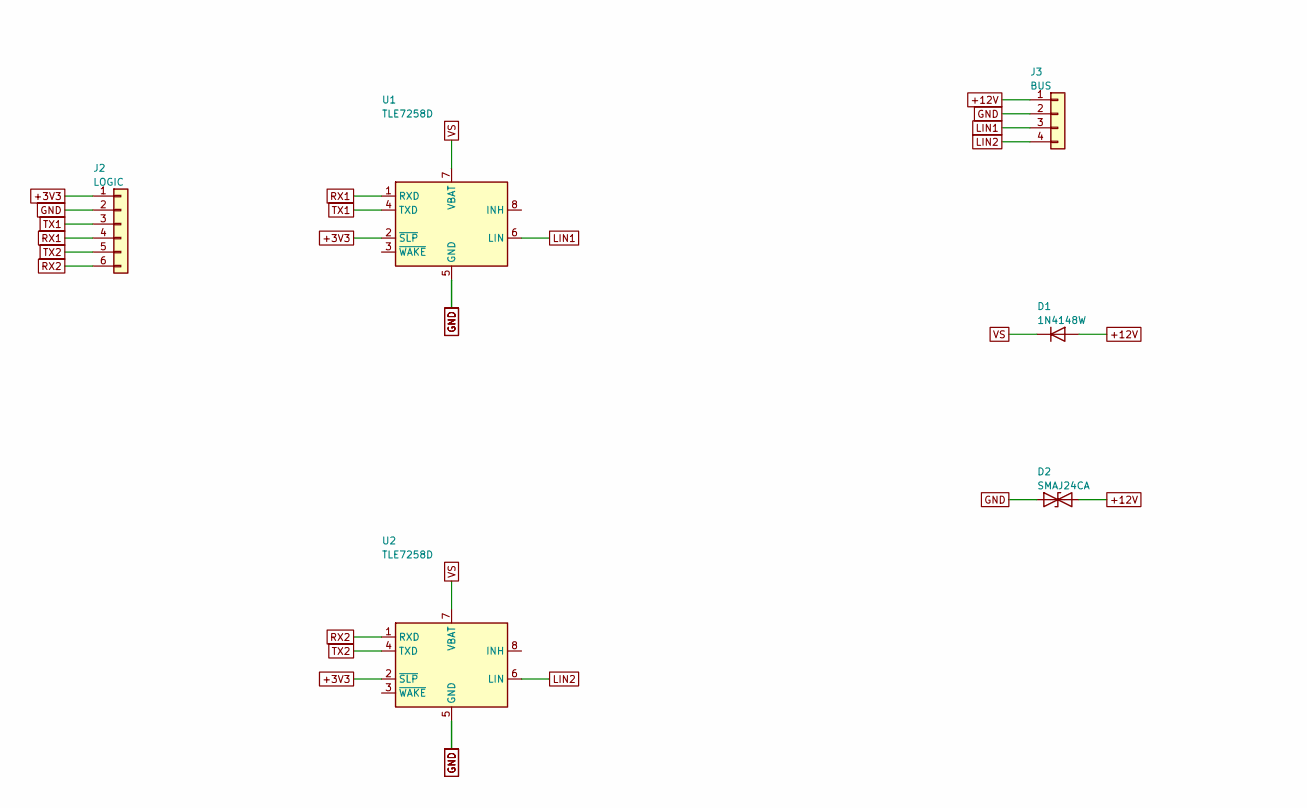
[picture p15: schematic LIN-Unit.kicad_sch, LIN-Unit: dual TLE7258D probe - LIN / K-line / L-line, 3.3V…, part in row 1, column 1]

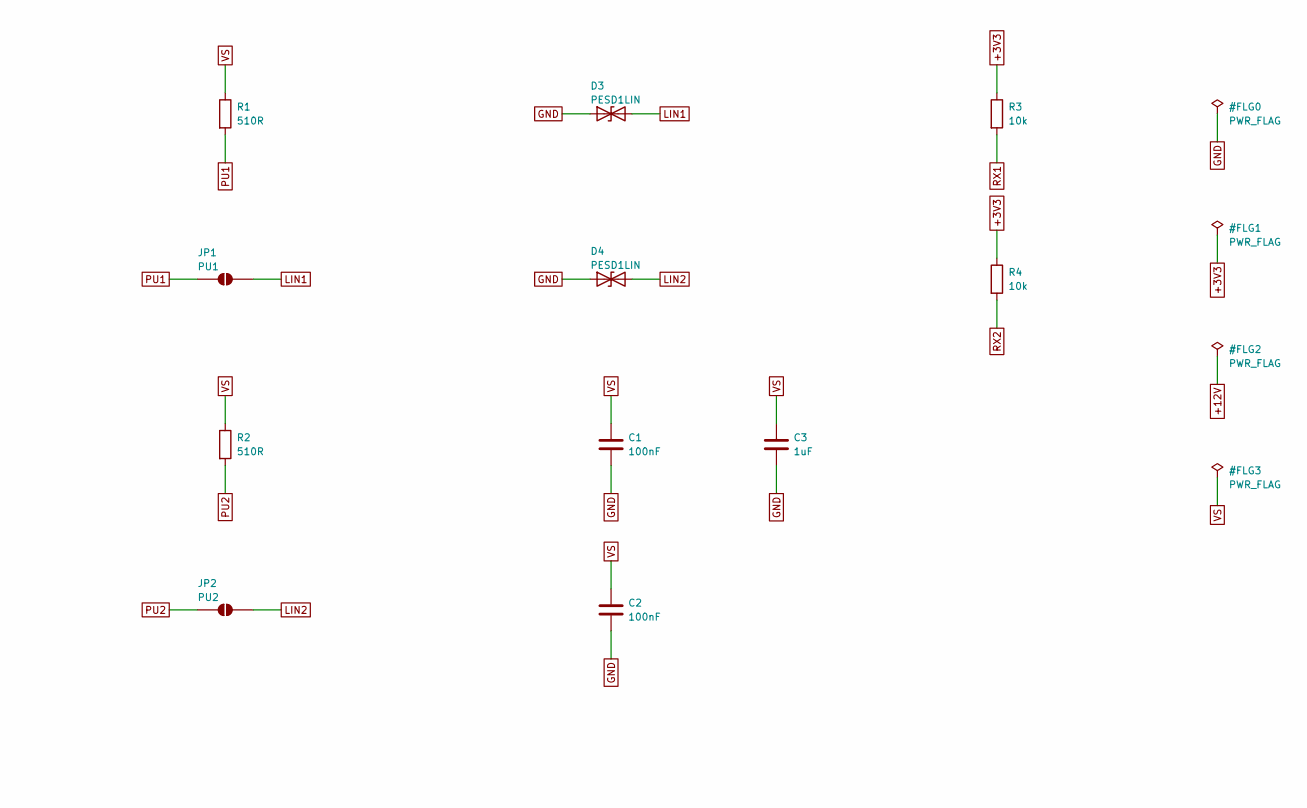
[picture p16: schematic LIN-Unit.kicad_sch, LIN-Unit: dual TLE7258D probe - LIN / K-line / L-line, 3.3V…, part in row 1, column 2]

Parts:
C1, C2: 100nF; C_0402_1005Metric
C3: 1uF; C_0603_1608Metric
D1: 1N4148W; D_SOD-123
D2: SMAJ24CA; D_SMA
D3, D4: PESD1LIN; D_SOD-323
J2: LOGIC; PinHeader_1x06_P2.54mm_Vertical
J3: BUS; PinHeader_1x04_P2.54mm_Vertical
JP1: PU1; SolderJumper-2_P1.3mm_Open_TrianglePad1.0x1.5mm
JP2: PU2; SolderJumper-2_P1.3mm_Open_TrianglePad1.0x1.5mm
R1, R2: 510R; R_0805_2012Metric
R3, R4: 10k; R_0402_1005Metric
U1, U2: TLE7258D; VSON-8-1EP_3x3mm_P0.65mm_EP1.6x2.4mm

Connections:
+3V3: J2.1, R3.1, R4.1, U1.2 (~SLP), U2.2 (~SLP)
+12V: D1.2 (A), D2.2 (A2), J3.1
GND: C1.2, C2.2, C3.2, D2.1 (A1), D3.1 (A1), D4.1 (A1), J2.2, J3.2, U1.5 (GND), U1.9 (GND), U2.5 (GND), U2.9 (GND)
LIN1: D3.2 (A2), J3.3, JP1.2 (B), U1.6 (LIN)
LIN2: D4.2 (A2), J3.4, JP2.2 (B), U2.6 (LIN)
PU1: JP1.1 (A), R1.2
PU2: JP2.1 (A), R2.2
RX1: J2.4, R3.2, U1.1 (RXD)
RX2: J2.6, R4.2, U2.1 (RXD)
TX1: J2.3, U1.4 (TXD)
TX2: J2.5, U2.4 (TXD)
VS: C1.1, C2.1, C3.1, D1.1 (K), R1.1, R2.1, U1.7 (VBAT), U2.7 (VBAT)

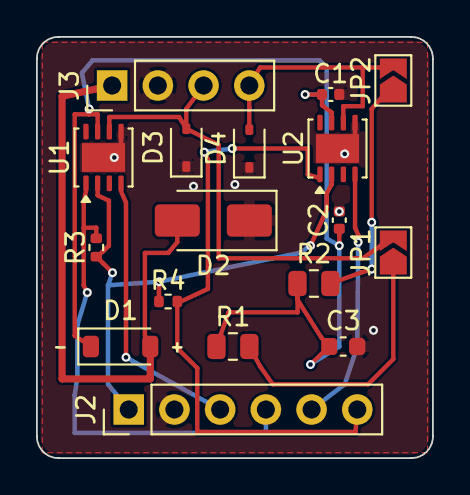
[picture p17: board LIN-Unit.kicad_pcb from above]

Board: 2 copper layers, 22.0 x 23.4 mm, 17 parts (0 on the bottom side), 12 nets.

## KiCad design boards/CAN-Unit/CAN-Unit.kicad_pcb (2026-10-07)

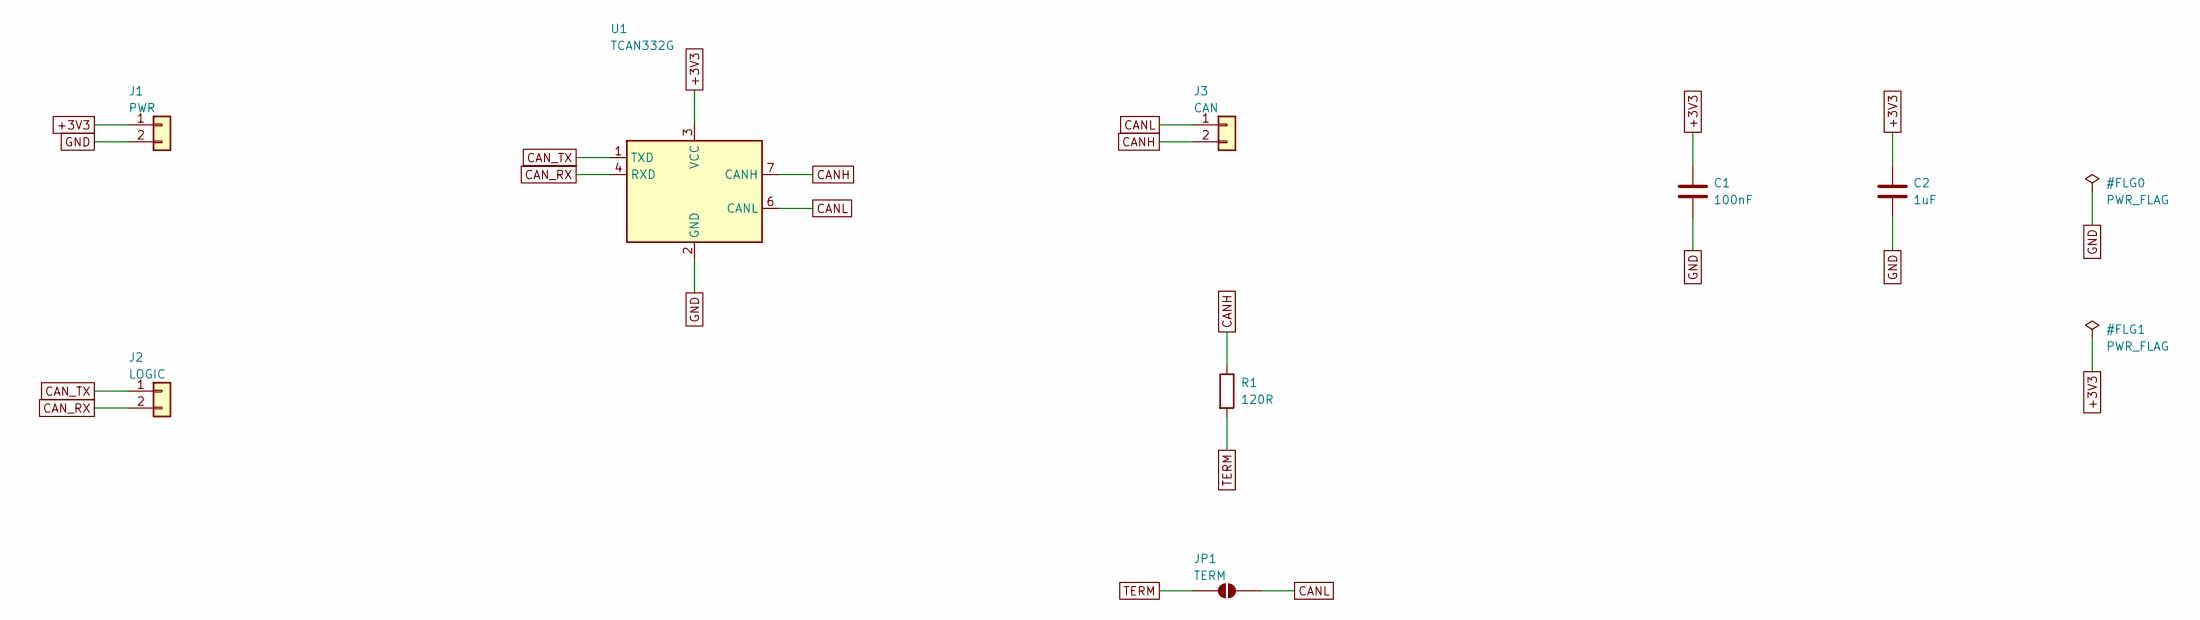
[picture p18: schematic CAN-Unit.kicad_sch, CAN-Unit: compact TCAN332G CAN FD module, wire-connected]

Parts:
C1: 100nF; C_0402_1005Metric
C2: 1uF; C_0603_1608Metric
J1: PWR; PinHeader_1x02_P2.54mm_Vertical
J2: LOGIC; PinHeader_1x02_P2.54mm_Vertical
J3: CAN; PinHeader_1x02_P2.54mm_Vertical
JP1: TERM; SolderJumper-2_P1.3mm_Open_TrianglePad1.0x1.5mm
R1: 120R; R_0603_1608Metric
U1: TCAN332G; SOT-23-8

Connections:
+3V3: C1.1, C2.1, J1.1, U1.3 (VCC)
CANH: J3.2, R1.1, U1.7 (CANH)
CANL: J3.1, JP1.2 (B), U1.6 (CANL)
CAN_RX: J2.2, U1.4 (RXD)
CAN_TX: J2.1, U1.1 (TXD)
GND: C1.2, C2.2, J1.2, U1.2 (GND)
TERM: JP1.1 (A), R1.2

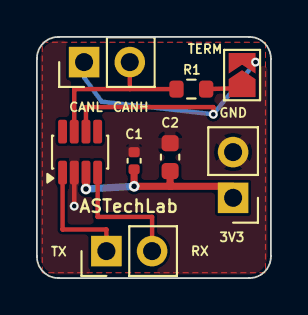
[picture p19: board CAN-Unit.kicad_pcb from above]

Board: 2 copper layers, 13.0 x 13.4 mm, 8 parts (0 on the bottom side), 7 nets.

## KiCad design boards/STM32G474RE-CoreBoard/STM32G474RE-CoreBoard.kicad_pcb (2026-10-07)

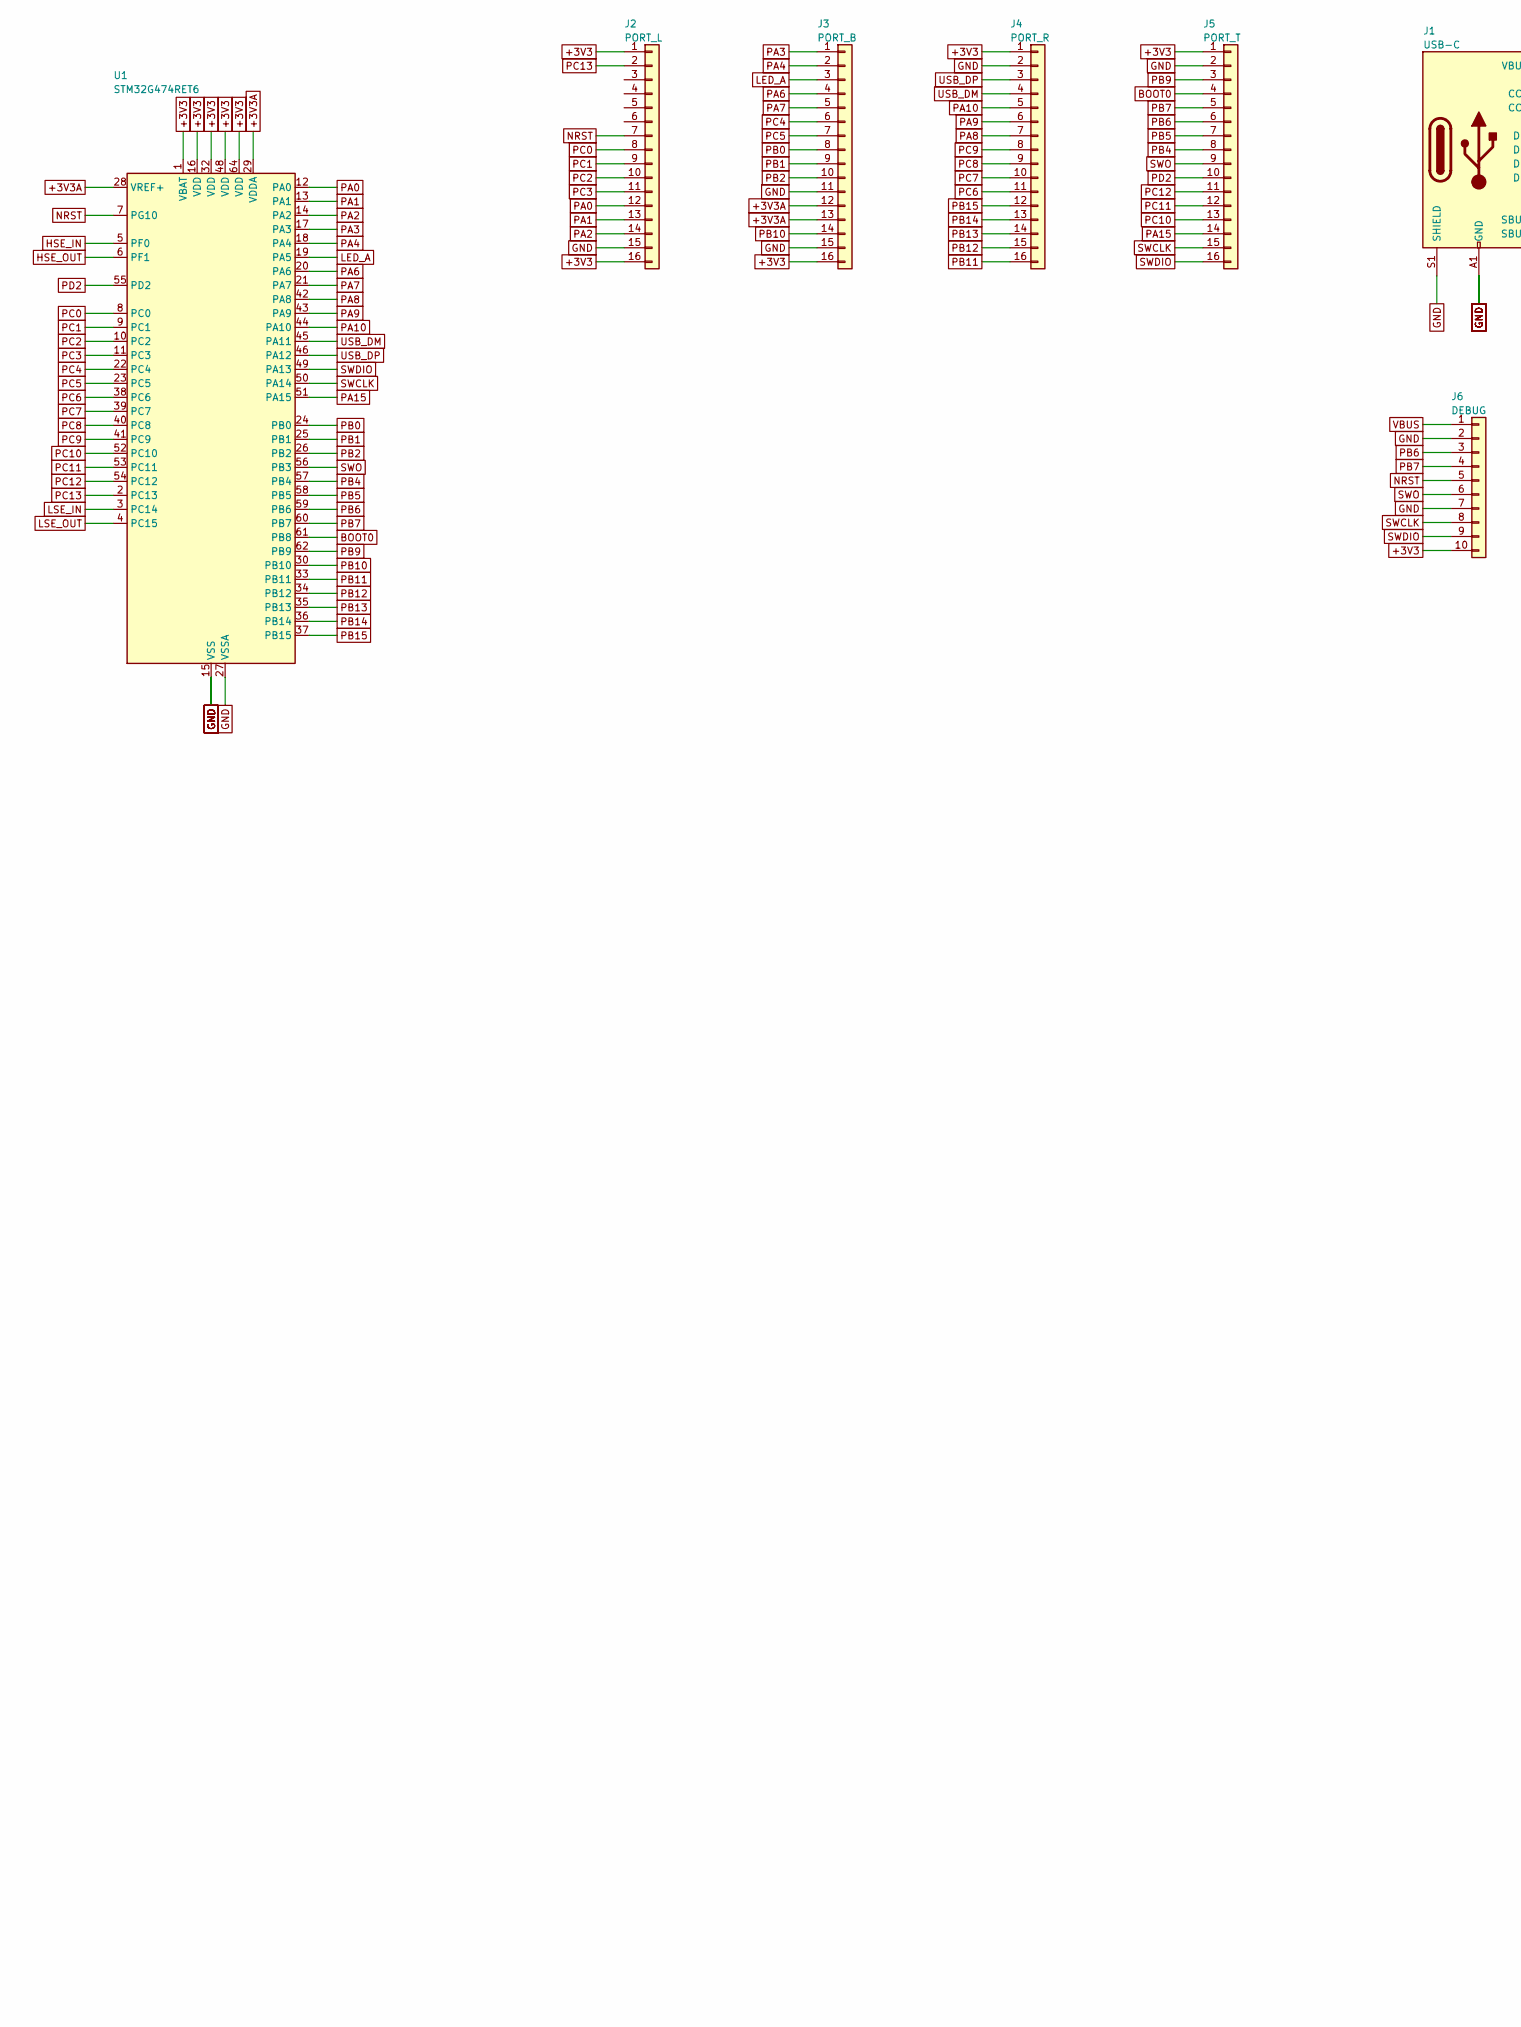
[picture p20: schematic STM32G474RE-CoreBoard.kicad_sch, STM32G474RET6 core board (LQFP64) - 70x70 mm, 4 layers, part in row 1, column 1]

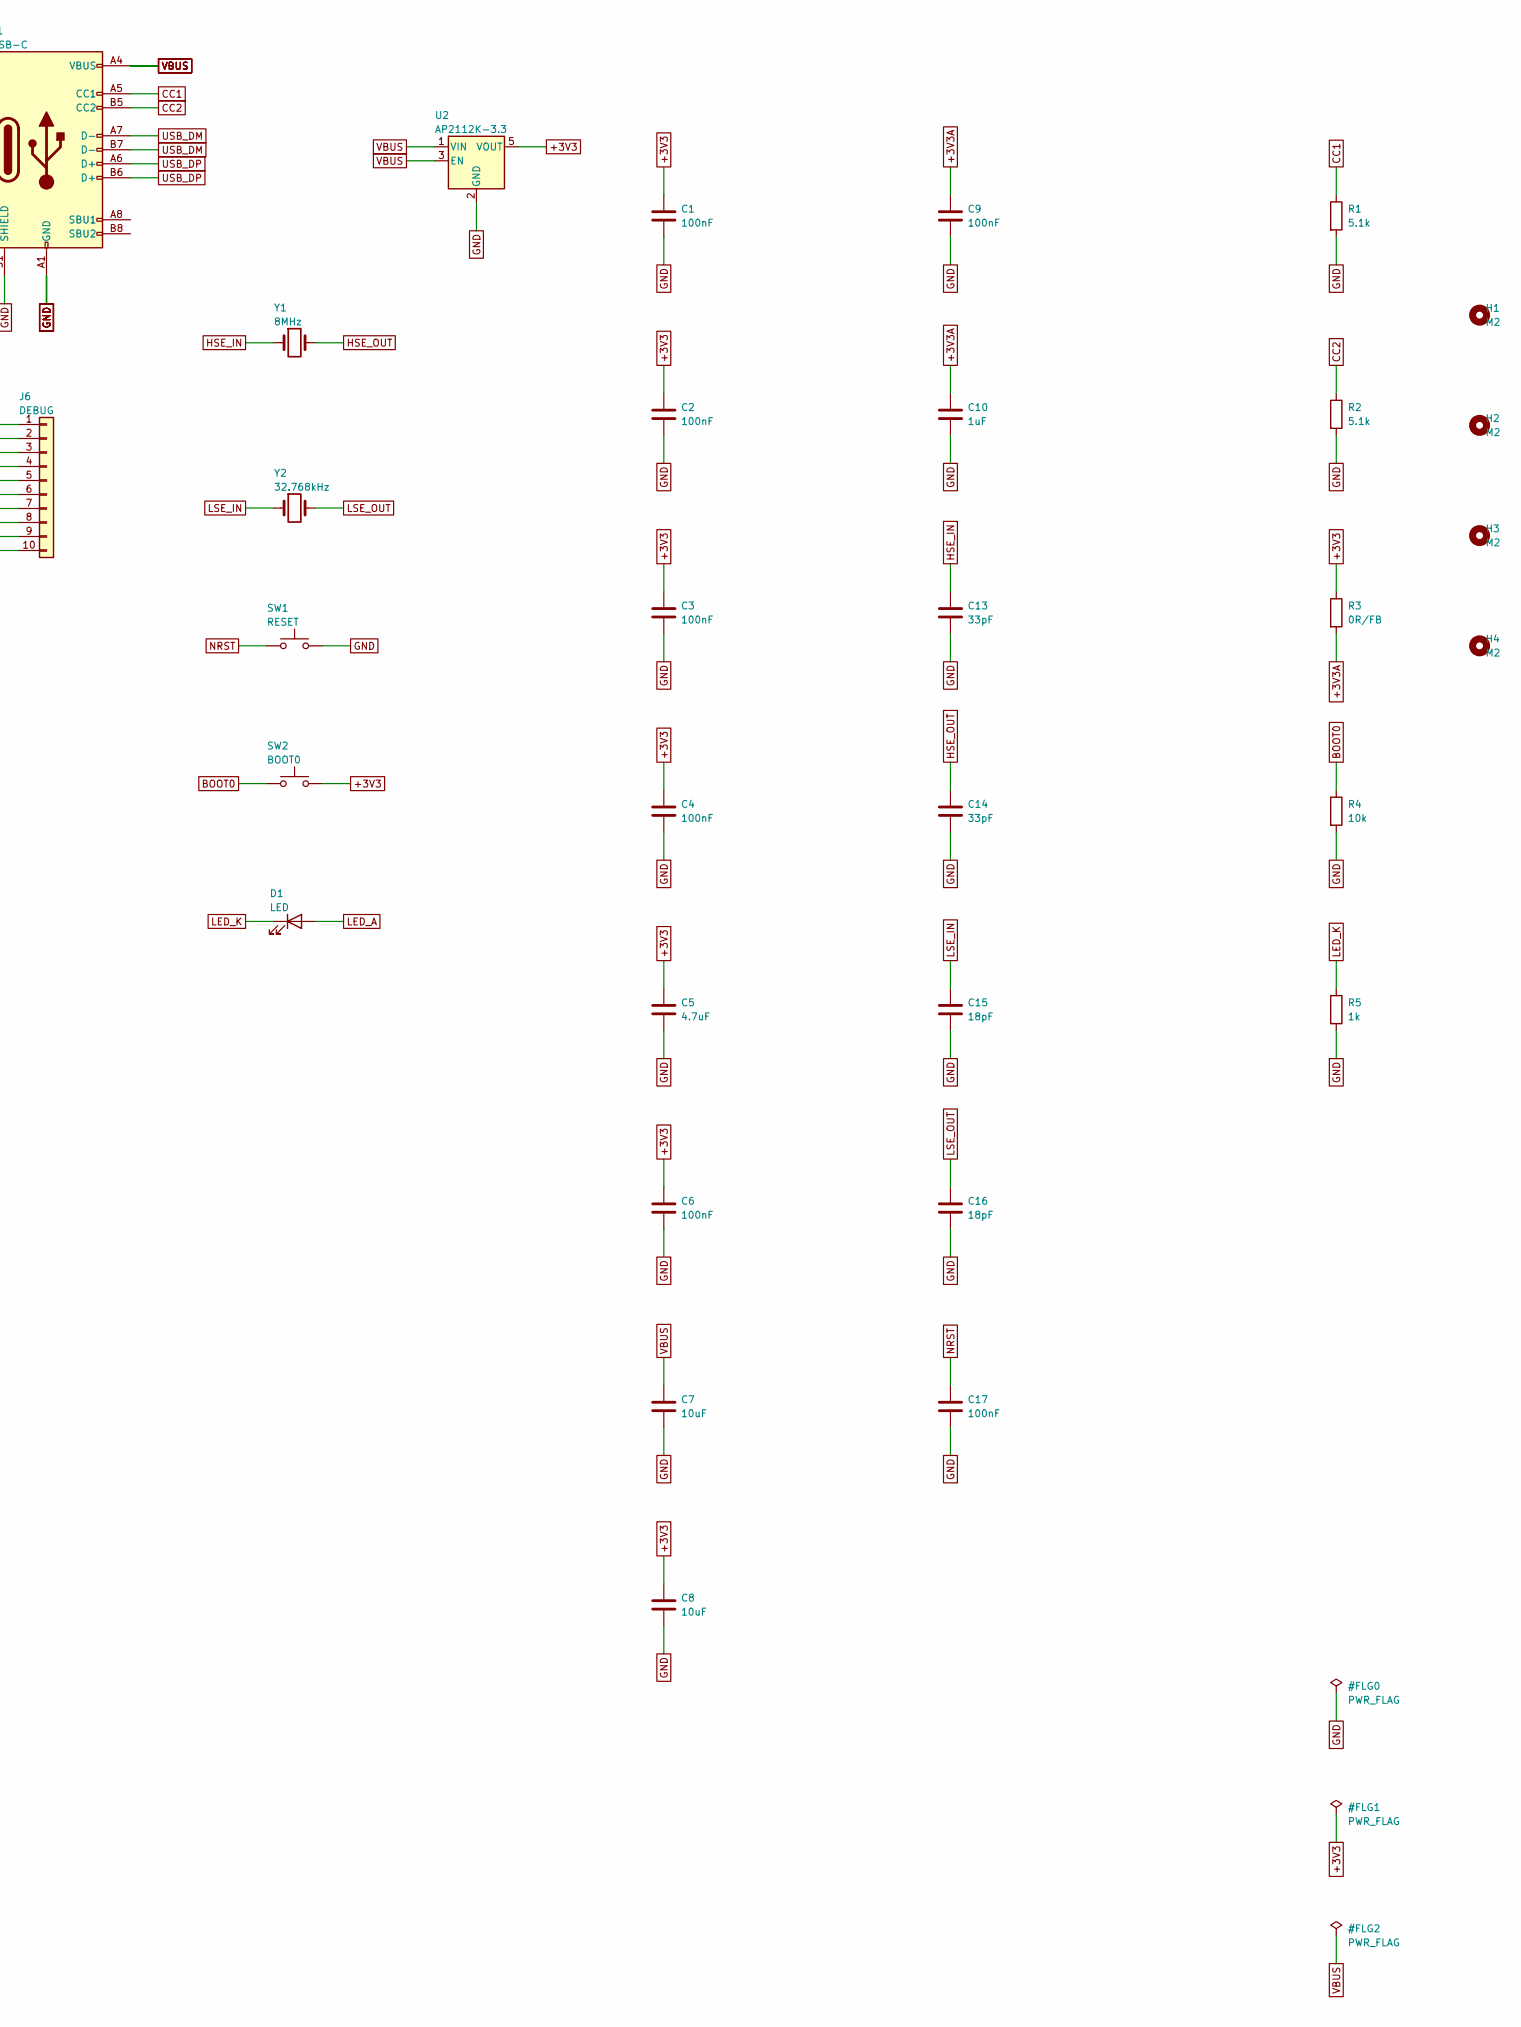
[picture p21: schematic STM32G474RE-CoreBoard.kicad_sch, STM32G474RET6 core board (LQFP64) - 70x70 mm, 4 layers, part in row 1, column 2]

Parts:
C1, C2, C3, C4, C9, C17: 100nF; C_0402_1005Metric
C5: 4.7uF; C_0805_2012Metric
C6: 100nF; C_0603_1608Metric
C7, C8: 10uF; C_0805_2012Metric
C10: 1uF; C_0603_1608Metric
C13, C14: 33pF; C_0402_1005Metric
C15, C16: 18pF; C_0402_1005Metric
D1: LED; LED_0805_2012Metric
H1, H2, H3, H4: M2; MountingHole_2.2mm_M2
J1: USB-C; USB_C_Receptacle_HRO_TYPE-C-31-M-12
J2: PORT_L; PinHeader_1x16_P2.54mm_Vertical
J3: PORT_B; PinHeader_1x16_P2.54mm_Vertical
J4: PORT_R; PinHeader_1x16_P2.54mm_Vertical
J5: PORT_T; PinHeader_1x16_P2.54mm_Vertical
J6: DEBUG; PinHeader_1x10_P2.54mm_Vertical
R1, R2: 5.1k; R_0402_1005Metric
R3: 0R/FB; R_0402_1005Metric
R4: 10k; R_0402_1005Metric
R5: 1k; R_0402_1005Metric
SW1: RESET; SW_SPST_SKQG_WithoutStem
SW2: BOOT0; SW_SPST_SKQG_WithoutStem
U1: STM32G474RET6; LQFP-64_10x10mm_P0.5mm
U2: AP2112K-3.3; SOT-23-5
Y1: 8MHz; Crystal_SMD_5032-2Pin_5.0x3.2mm
Y2: 32.768kHz; Crystal_SMD_MicroCrystal_CC7V-T1A-2Pin_3.2x1.5mm

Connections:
+3V3: C1.1, C2.1, C3.1, C4.1, C5.1, C6.1, C8.1, J2.1, J2.16, J3.16, J4.1, J5.1, J6.10, R3.1, SW2.2, U1.1 (VBAT), U1.16 (VDD), U1.32 (VDD), U1.48 (VDD), U1.64 (VDD), U2.5 (VOUT)
+3V3A: C9.1, C10.1, J3.12, J3.13, R3.2, U1.28 (VREF+), U1.29 (VDDA)
BOOT0: J5.4, R4.1, SW2.1, U1.61 (PB8)
CC1: J1.A5 (CC1), R1.1
CC2: J1.B5 (CC2), R2.1
GND: C1.2, C2.2, C3.2, C4.2, C5.2, C6.2, C7.2, C8.2, C9.2, C10.2, C13.2, C14.2, C15.2, C16.2, C17.2, J1.A1 (GND), J1.A12 (GND), J1.B1 (GND), J1.B12 (GND), J1.S1 (SHIELD), J2.15, J3.11, J3.15, J4.2, J5.2, J6.2, J6.7, R1.2, R2.2, R4.2, R5.2, SW1.2, U1.15 (VSS), U1.27 (VSSA), U1.31 (VSS), U1.47 (VSS), U1.63 (VSS), U2.2 (GND)
HSE_IN: C13.1, U1.5 (PF0), Y1.1
HSE_OUT: C14.1, U1.6 (PF1), Y1.2
LED_A: D1.2 (A), J3.3, U1.19 (PA5)
LED_K: D1.1 (K), R5.1
LSE_IN: C15.1, U1.3 (PC14), Y2.1
LSE_OUT: C16.1, U1.4 (PC15), Y2.2
NRST: C17.1, J2.7, J6.5, SW1.1, U1.7 (PG10)
PA0: J2.12, U1.12 (PA0)
PA1: J2.13, U1.13 (PA1)
PA2: J2.14, U1.14 (PA2)
PA3: J3.1, U1.17 (PA3)
PA4: J3.2, U1.18 (PA4)
PA6: J3.4, U1.20 (PA6)
PA7: J3.5, U1.21 (PA7)
PA8: J4.7, U1.42 (PA8)
PA9: J4.6, U1.43 (PA9)
PA10: J4.5, U1.44 (PA10)
PA15: J5.14, U1.51 (PA15)
PB0: J3.8, U1.24 (PB0)
PB1: J3.9, U1.25 (PB1)
PB2: J3.10, U1.26 (PB2)
PB4: J5.8, U1.57 (PB4)
PB5: J5.7, U1.58 (PB5)
PB6: J5.6, J6.3, U1.59 (PB6)
PB7: J5.5, J6.4, U1.60 (PB7)
PB9: J5.3, U1.62 (PB9)
PB10: J3.14, U1.30 (PB10)
PB11: J4.16, U1.33 (PB11)
PB12: J4.15, U1.34 (PB12)
PB13: J4.14, U1.35 (PB13)
PB14: J4.13, U1.36 (PB14)
PB15: J4.12, U1.37 (PB15)
PC0: J2.8, U1.8 (PC0)
PC1: J2.9, U1.9 (PC1)
PC2: J2.10, U1.10 (PC2)
PC3: J2.11, U1.11 (PC3)
PC4: J3.6, U1.22 (PC4)
PC5: J3.7, U1.23 (PC5)
PC6: J4.11, U1.38 (PC6)
PC7: J4.10, U1.39 (PC7)
PC8: J4.9, U1.40 (PC8)
PC9: J4.8, U1.41 (PC9)
PC10: J5.13, U1.52 (PC10)
PC11: J5.12, U1.53 (PC11)
PC12: J5.11, U1.54 (PC12)
PC13: J2.2, U1.2 (PC13)
PD2: J5.10, U1.55 (PD2)
SWCLK: J5.15, J6.8, U1.50 (PA14)
SWDIO: J5.16, J6.9, U1.49 (PA13)
SWO: J5.9, J6.6, U1.56 (PB3)
USB_DM: J1.A7 (D-), J1.B7 (D-), J4.4, U1.45 (PA11)
USB_DP: J1.A6 (D+), J1.B6 (D+), J4.3, U1.46 (PA12)
VBUS: C7.1, J1.A4 (VBUS), J1.A9 (VBUS), J1.B4 (VBUS), J1.B9 (VBUS), J6.1, U2.1 (VIN), U2.3 (EN)

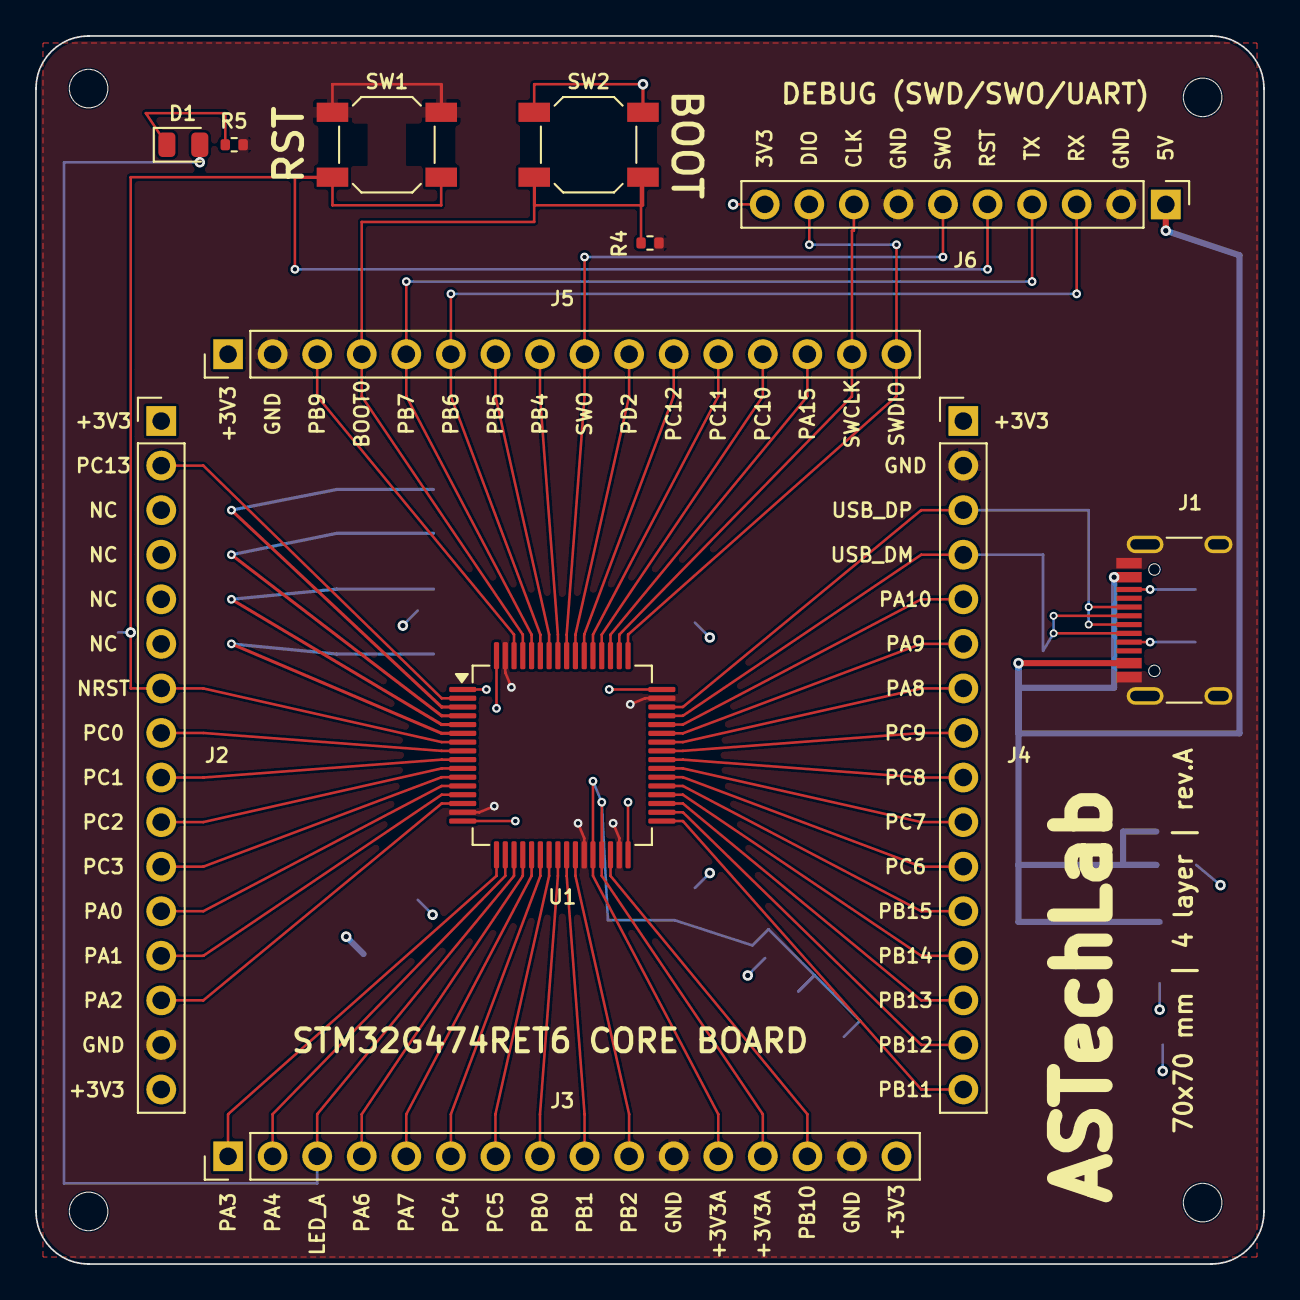
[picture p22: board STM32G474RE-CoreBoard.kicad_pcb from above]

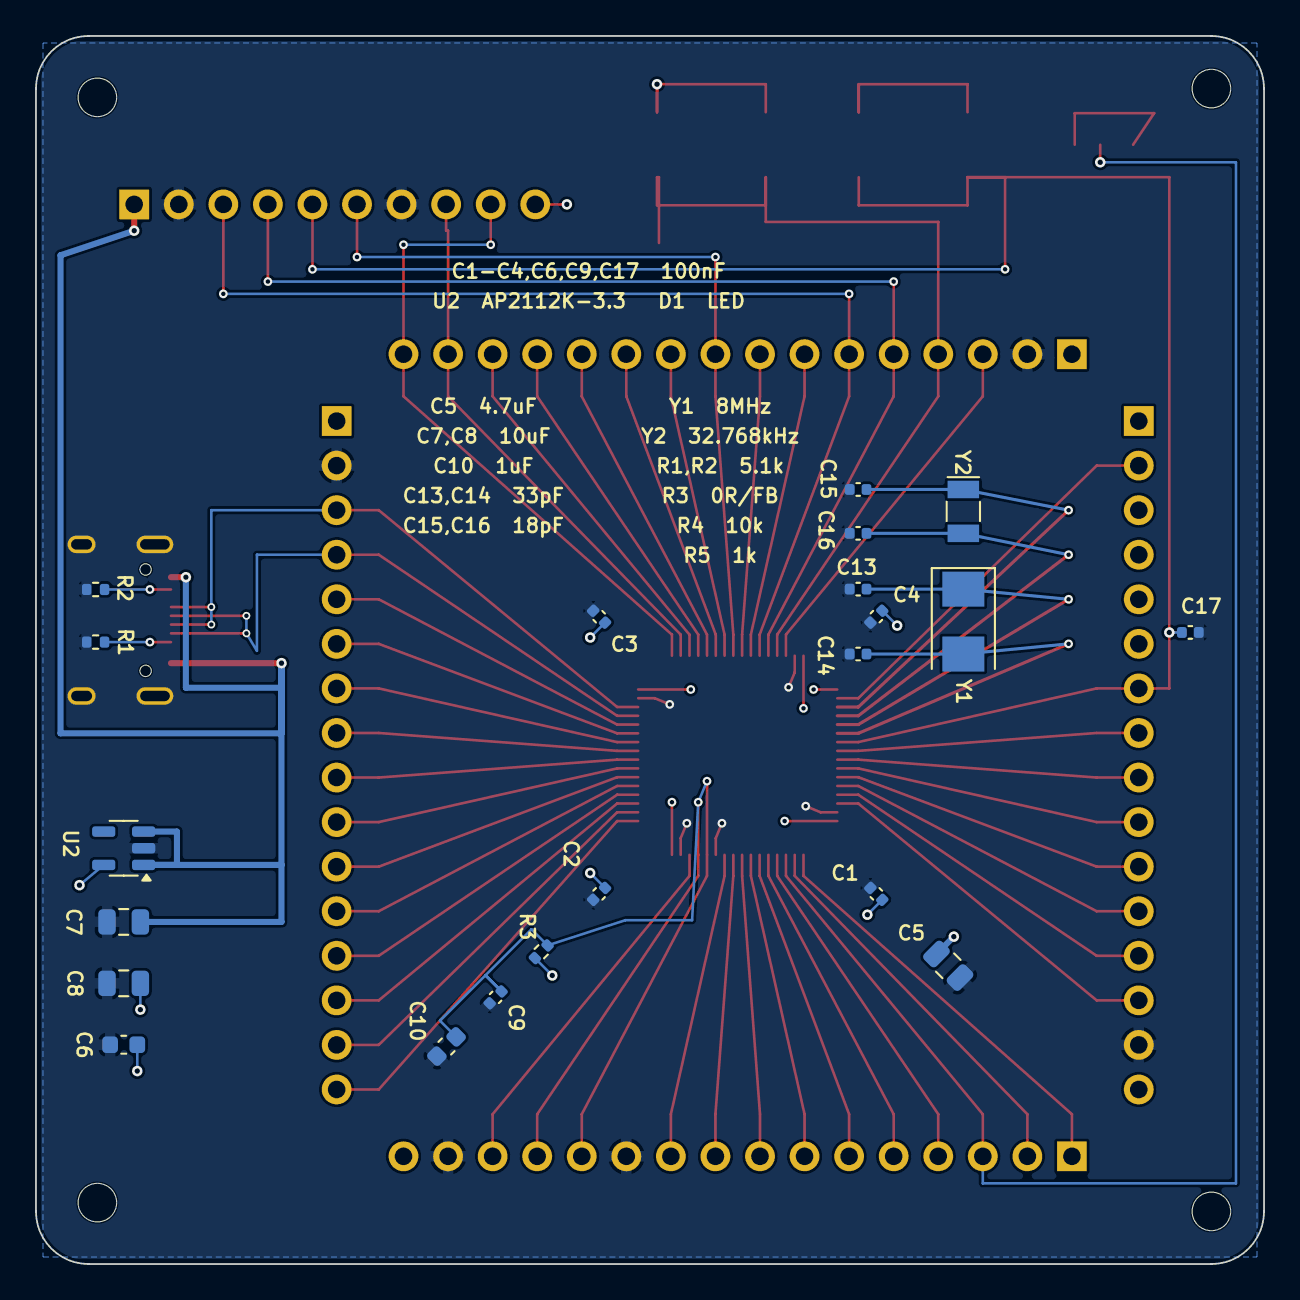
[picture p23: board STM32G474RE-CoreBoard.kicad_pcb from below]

Board: 4 copper layers, 70.0 x 70.0 mm, 37 parts (21 on the bottom side), 59 nets.

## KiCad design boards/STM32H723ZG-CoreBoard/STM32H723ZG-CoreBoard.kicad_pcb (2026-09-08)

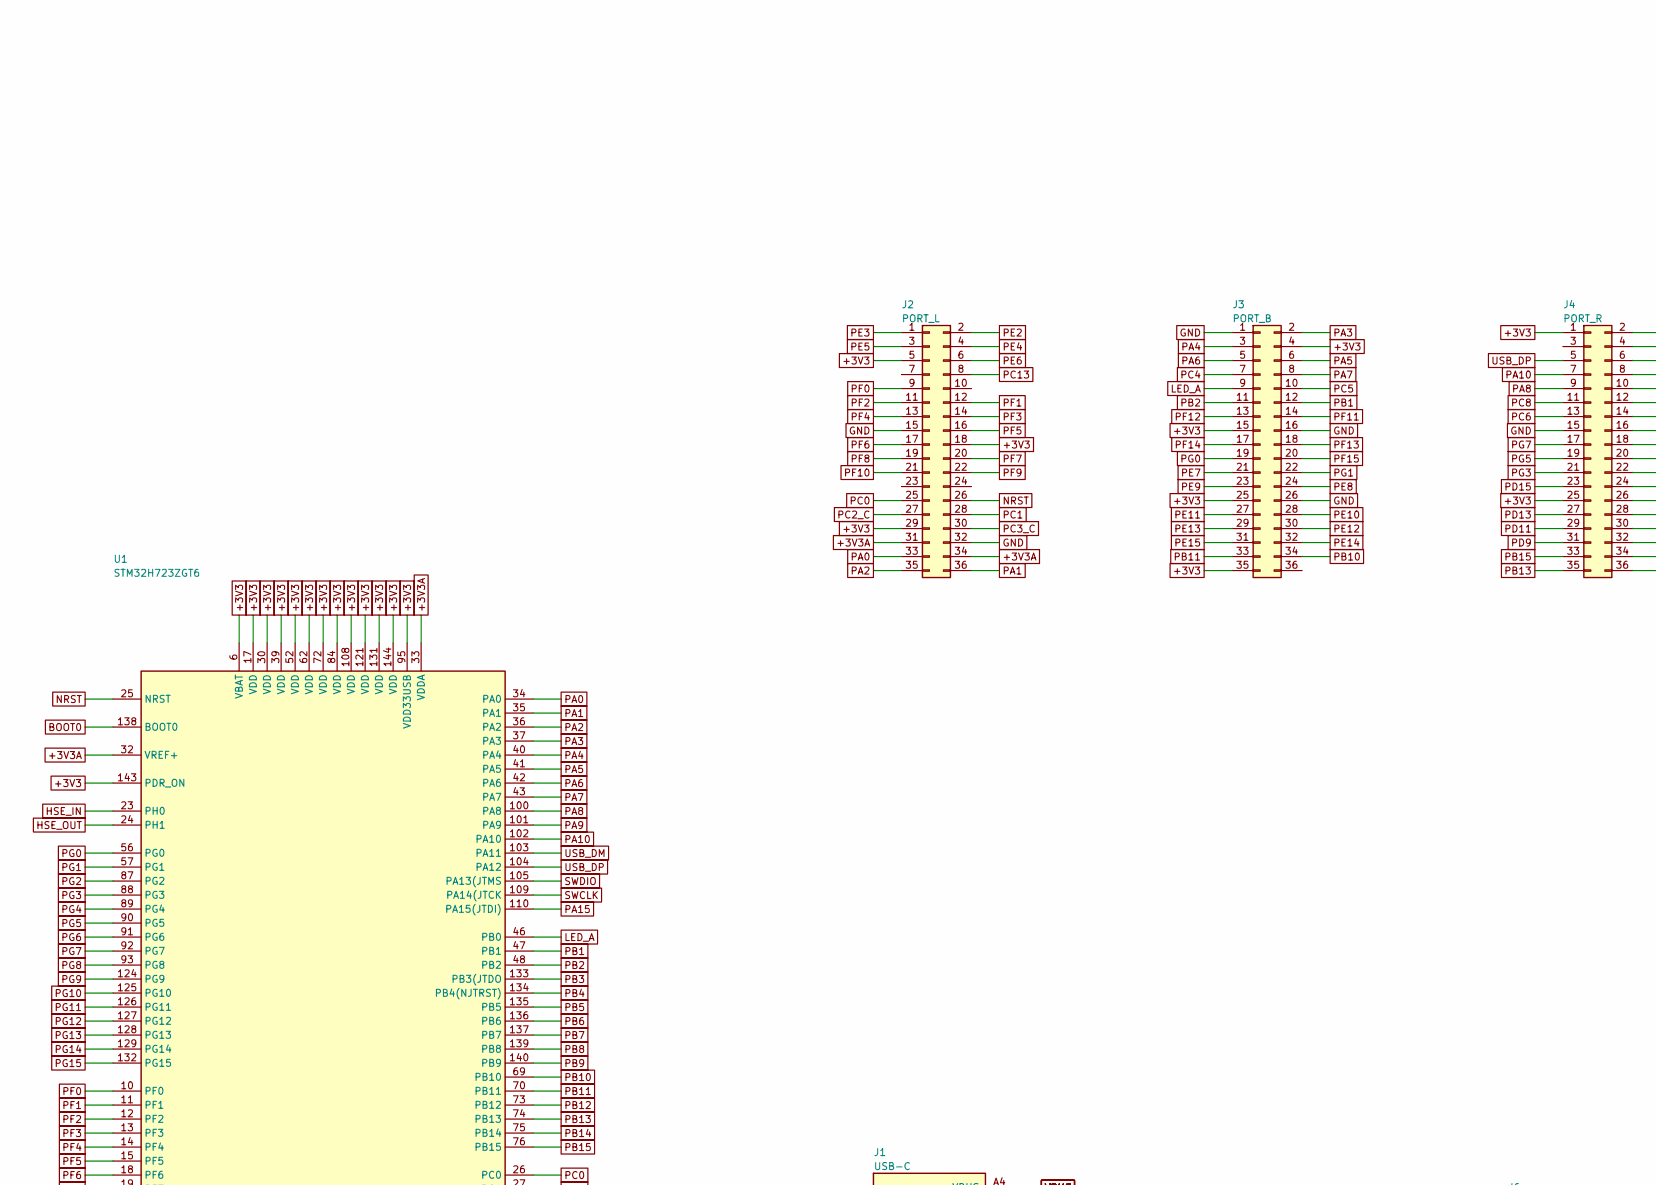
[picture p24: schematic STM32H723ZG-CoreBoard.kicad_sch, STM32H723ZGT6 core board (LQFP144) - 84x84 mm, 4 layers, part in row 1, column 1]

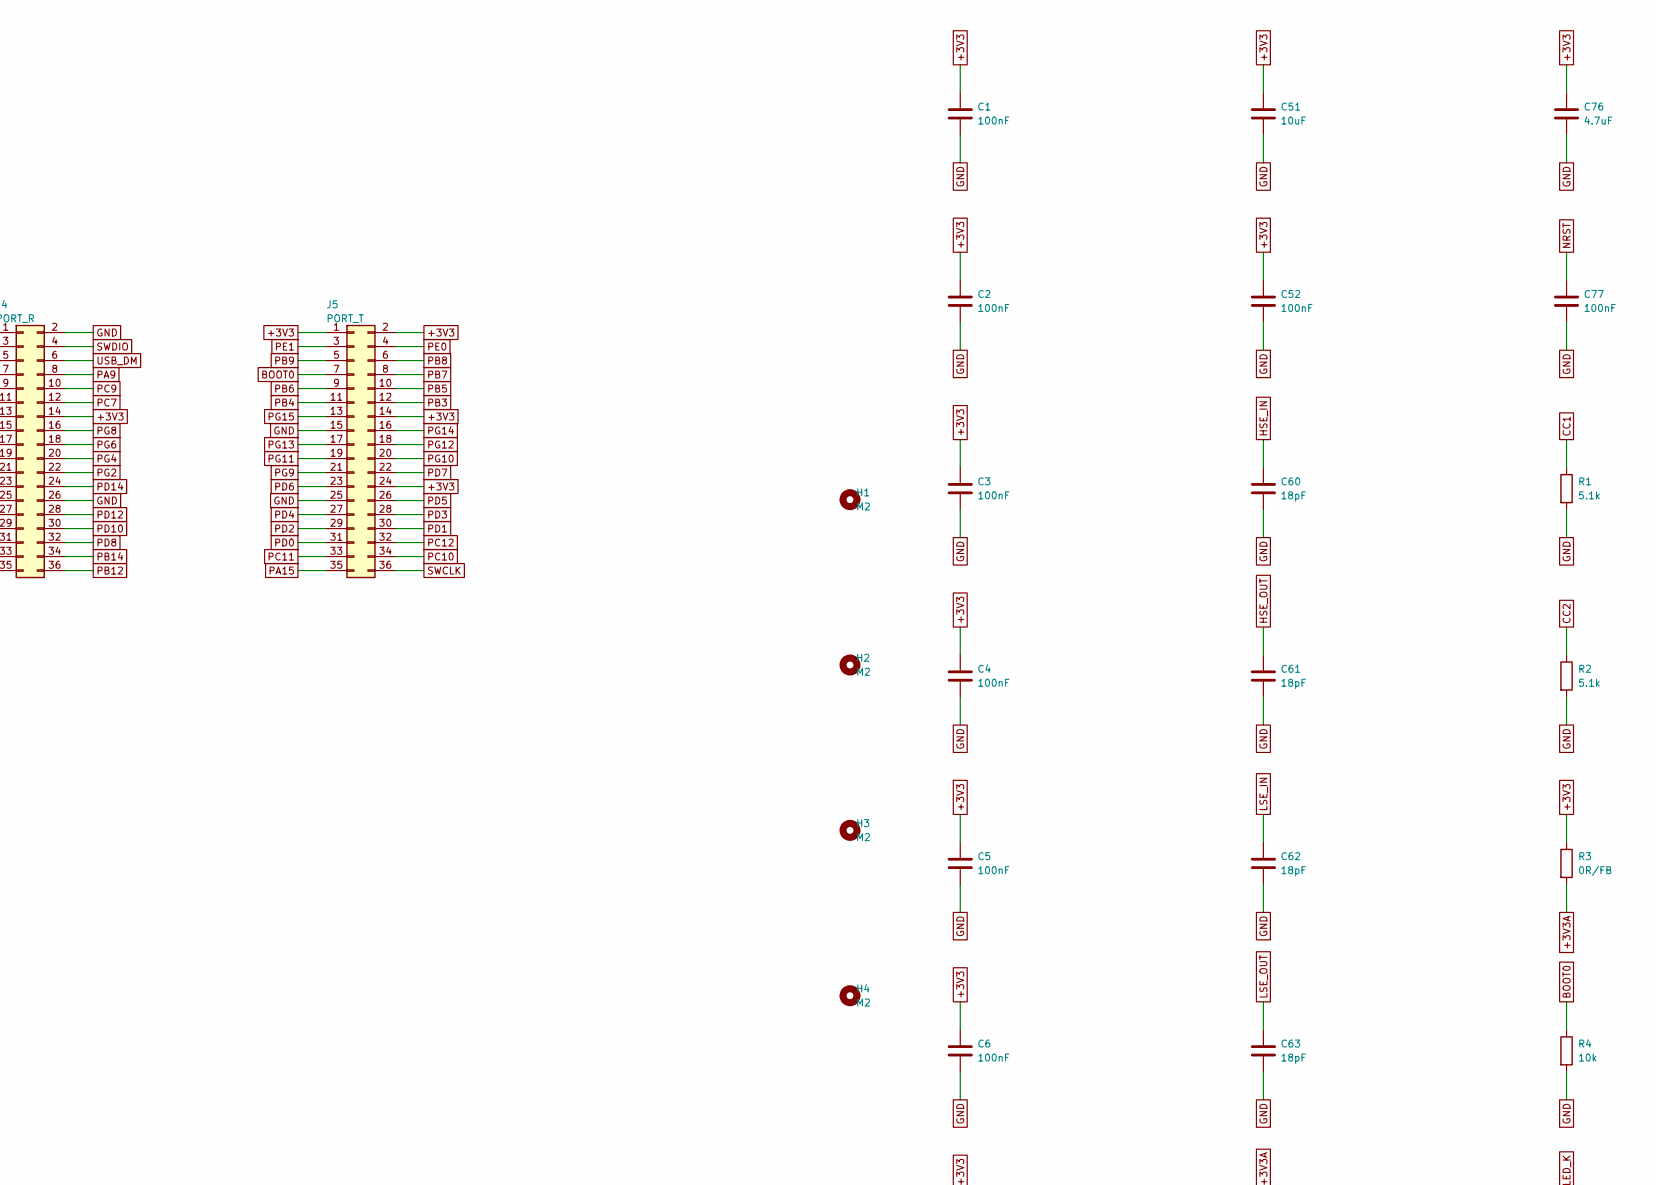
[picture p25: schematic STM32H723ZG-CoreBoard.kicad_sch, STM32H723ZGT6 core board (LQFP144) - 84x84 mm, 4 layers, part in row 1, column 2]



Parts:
C1, C2, C3, C4, C5, C6, C7, C8, C9, C10, C11, C70, C74, C77: 100nF; C_0402_1005Metric
C50, C51: 10uF; C_0805_2012Metric
C52: 100nF; C_0603_1608Metric
C60, C61, C62, C63: 18pF; C_0402_1005Metric
C71: 1uF; C_0603_1608Metric
C72, C73: 2.2uF; C_0603_1608Metric
C75, C76: 4.7uF; C_0805_2012Metric
D1: LED; LED_0805_2012Metric
H1, H2, H3, H4: M2; MountingHole_2.2mm_M2
J1: USB-C; USB_C_Receptacle_HRO_TYPE-C-31-M-12
J2: PORT_L; PinHeader_2x18_P2.54mm_Vertical
J3: PORT_B; PinHeader_2x18_P2.54mm_Vertical
J4: PORT_R; PinHeader_2x18_P2.54mm_Vertical
J5: PORT_T; PinHeader_2x18_P2.54mm_Vertical
J6: DEBUG; PinHeader_1x10_P2.54mm_Vertical
R1, R2: 5.1k; R_0402_1005Metric
R3: 0R/FB; R_0402_1005Metric
R4: 10k; R_0402_1005Metric
R5: 1k; R_0402_1005Metric
SW1: RESET; SW_SPST_SKQG_WithoutStem
SW2: BOOT0; SW_SPST_SKQG_WithoutStem
U1: STM32H723ZGT6; LQFP-144_20x20mm_P0.5mm
U2: AP2112K-3.3; SOT-23-5
Y1: 25MHz; Crystal_SMD_3225-4Pin_3.2x2.5mm
Y2: 32.768kHz; Crystal_SMD_MicroCrystal_CC7V-T1A-2Pin_3.2x1.5mm

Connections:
+3V3: C1.1, C2.1, C3.1, C4.1, C5.1, C6.1, C7.1, C8.1, C9.1, C10.1, C11.1, C51.1, C52.1, C74.1, C75.1, C76.1, J2.5, J2.18, J2.29, J3.4, J3.15, J3.25, J3.35, J4.1, J4.14, J4.25, J5.1, J5.2, J5.14, J5.24, J6.10, R3.1, SW2.2, U1.6 (VBAT), U1.17 (VDD), U1.30 (VDD), U1.39 (VDD), U1.52 (VDD), U1.62 (VDD), U1.72 (VDD), U1.84 (VDD), U1.95 (VDD33USB), U1.108 (VDD), U1.121 (VDD), U1.131 (VDD), U1.143 (PDR_ON), U1.144 (VDD), U2.5 (VOUT)
+3V3A: C70.1, C71.1, J2.31, J2.34, R3.2, U1.32 (VREF+), U1.33 (VDDA)
BOOT0: J5.7, R4.1, SW2.1, U1.138 (BOOT0)
CC1: J1.A5 (CC1), R1.1
CC2: J1.B5 (CC2), R2.1
GND: C1.2, C2.2, C3.2, C4.2, C5.2, C6.2, C7.2, C8.2, C9.2, C10.2, C11.2, C50.2, C51.2, C52.2, C60.2, C61.2, C62.2, C63.2, C70.2, C71.2, C72.2, C73.2, C74.2, C75.2, C76.2, C77.2, J1.A1 (GND), J1.A12 (GND), J1.B1 (GND), J1.B12 (GND), J1.SH (SHIELD), J2.15, J2.32, J3.1, J3.16, J3.26, J4.2, J4.15, J4.26, J5.15, J5.25, J6.2, J6.7, R1.2, R2.2, R4.2, R5.2, SW1.2, U1.16 (VSS), U1.31 (VSSA), U1.38 (VSS), U1.51 (VSS), U1.61 (VSS), U1.83 (VSS), U1.94 (VSS), U1.107 (VSS), U1.120 (VSS), U1.130 (VSS), U2.2 (GND), Y1.2 (G), Y1.4 (G)
HSE_IN: C60.1, U1.23 (PH0), Y1.1
HSE_OUT: C61.1, U1.24 (PH1), Y1.3
LED_A: D1.2 (A), J3.9, U1.46 (PB0)
LED_K: D1.1 (K), R5.1
LSE_IN: C62.1, U1.8 (PC14), Y2.1
LSE_OUT: C63.1, U1.9 (PC15), Y2.2
NRST: C77.1, J2.26, J6.5, SW1.1, U1.25 (NRST)
PA0: J2.33, U1.34 (PA0)
PA1: J2.36, U1.35 (PA1)
PA2: J2.35, U1.36 (PA2)
PA3: J3.2, U1.37 (PA3)
PA4: J3.3, U1.40 (PA4)
PA5: J3.6, U1.41 (PA5)
PA6: J3.5, U1.42 (PA6)
PA7: J3.8, U1.43 (PA7)
PA8: J4.9, U1.100 (PA8)
PA9: J4.8, U1.101 (PA9)
PA10: J4.7, U1.102 (PA10)
PA15: J5.35, U1.110 (PA15(JTDI))
PB1: J3.12, U1.47 (PB1)
PB2: J3.11, U1.48 (PB2)
PB3: J5.12, J6.6, U1.133 (PB3(JTDO)
PB4: J5.11, U1.134 (PB4(NJTRST))
PB5: J5.10, U1.135 (PB5)
PB6: J5.9, U1.136 (PB6)
PB7: J5.8, U1.137 (PB7)
PB8: J5.6, U1.139 (PB8)
PB9: J5.5, U1.140 (PB9)
PB10: J3.34, U1.69 (PB10)
PB11: J3.33, U1.70 (PB11)
PB12: J4.36, U1.73 (PB12)
PB13: J4.35, U1.74 (PB13)
PB14: J4.34, U1.75 (PB14)
PB15: J4.33, U1.76 (PB15)
PC0: J2.25, U1.26 (PC0)
PC1: J2.28, U1.27 (PC1)
PC2_C: J2.27, U1.28 (PC2_C)
PC3_C: J2.30, U1.29 (PC3_C)
PC4: J3.7, U1.44 (PC4)
PC5: J3.10, U1.45 (PC5)
PC6: J4.13, U1.96 (PC6)
PC7: J4.12, U1.97 (PC7)
PC8: J4.11, U1.98 (PC8)
PC9: J4.10, U1.99 (PC9)
PC10: J5.34, J6.3, U1.111 (PC10)
PC11: J5.33, J6.4, U1.112 (PC11)
PC12: J5.32, U1.113 (PC12)
PC13: J2.8, U1.7 (PC13)
PD0: J5.31, U1.114 (PD0)
PD1: J5.30, U1.115 (PD1)
PD2: J5.29, U1.116 (PD2)
PD3: J5.28, U1.117 (PD3)
PD4: J5.27, U1.118 (PD4)
PD5: J5.26, U1.119 (PD5)
PD6: J5.23, U1.122 (PD6)
PD7: J5.22, U1.123 (PD7)
PD8: J4.32, U1.77 (PD8)
PD9: J4.31, U1.78 (PD9)
PD10: J4.30, U1.79 (PD10)
PD11: J4.29, U1.80 (PD11)
PD12: J4.28, U1.81 (PD12)
PD13: J4.27, U1.82 (PD13)
PD14: J4.24, U1.85 (PD14)
PD15: J4.23, U1.86 (PD15)
PE0: J5.4, U1.141 (PE0)
PE1: J5.3, U1.142 (PE1)
PE2: J2.2, U1.1 (PE2)
PE3: J2.1, U1.2 (PE3)
PE4: J2.4, U1.3 (PE4)
PE5: J2.3, U1.4 (PE5)
PE6: J2.6, U1.5 (PE6)
PE7: J3.21, U1.58 (PE7)
PE8: J3.24, U1.59 (PE8)
PE9: J3.23, U1.60 (PE9)
PE10: J3.28, U1.63 (PE10)
PE11: J3.27, U1.64 (PE11)
PE12: J3.30, U1.65 (PE12)
PE13: J3.29, U1.66 (PE13)
PE14: J3.32, U1.67 (PE14)
PE15: J3.31, U1.68 (PE15)
PF0: J2.9, U1.10 (PF0)
PF1: J2.12, U1.11 (PF1)
PF2: J2.11, U1.12 (PF2)
PF3: J2.14, U1.13 (PF3)
PF4: J2.13, U1.14 (PF4)
PF5: J2.16, U1.15 (PF5)
PF6: J2.17, U1.18 (PF6)
PF7: J2.20, U1.19 (PF7)
PF8: J2.19, U1.20 (PF8)
PF9: J2.22, U1.21 (PF9)
PF10: J2.21, U1.22 (PF10)
PF11: J3.14, U1.49 (PF11)
PF12: J3.13, U1.50 (PF12)
PF13: J3.18, U1.53 (PF13)
PF14: J3.17, U1.54 (PF14)
PF15: J3.20, U1.55 (PF15)
PG0: J3.19, U1.56 (PG0)
PG1: J3.22, U1.57 (PG1)
PG2: J4.22, U1.87 (PG2)
PG3: J4.21, U1.88 (PG3)
PG4: J4.20, U1.89 (PG4)
PG5: J4.19, U1.90 (PG5)
PG6: J4.18, U1.91 (PG6)
PG7: J4.17, U1.92 (PG7)
PG8: J4.16, U1.93 (PG8)
PG9: J5.21, U1.124 (PG9)
PG10: J5.20, U1.125 (PG10)
PG11: J5.19, U1.126 (PG11)
PG12: J5.18, U1.127 (PG12)
PG13: J5.17, U1.128 (PG13)
PG14: J5.16, U1.129 (PG14)
PG15: J5.13, U1.132 (PG15)
SWCLK: J5.36, J6.8, U1.109 (PA14(JTCK)
SWDIO: J4.4, J6.9, U1.105 (PA13(JTMS)
USB_DM: J1.A7 (D-), J1.B7 (D-), J4.6, U1.103 (PA11)
USB_DP: J1.A6 (D+), J1.B6 (D+), J4.5, U1.104 (PA12)
VBUS: C50.1, J1.A4 (VBUS), J1.A9 (VBUS), J1.B4 (VBUS), J1.B9 (VBUS), J6.1, U2.1 (VIN), U2.3 (EN)
VCAP1: C72.1, U1.71 (VCAP)
VCAP2: C73.1, U1.106 (VCAP)



Board: 4 copper layers, 84.0 x 84.0 mm, 48 parts (32 on the bottom side), 125 nets.

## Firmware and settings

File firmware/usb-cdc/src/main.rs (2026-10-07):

#![no_std]
#![no_main]

use defmt::{info, panic};
use embassy_executor::Spawner;
use embassy_futures::join::join;
use embassy_stm32::gpio::{Level, Output, Speed};
use embassy_stm32::usb::{Driver, Instance};
use embassy_stm32::{bind_interrupts, peripherals, usb, Config};
use embassy_usb::class::cdc_acm::{CdcAcmClass, State};
use embassy_usb::driver::EndpointError;
use embassy_usb::Builder;
use {defmt_rtt as _, panic_probe as _};

bind_interrupts!(struct Irqs {
    OTG_HS => usb::InterruptHandler<peripherals::USB_OTG_HS>;
});

#[embassy_executor::main]
async fn main(_spawner: Spawner) {
    let mut config = Config::default();
    {
        use embassy_stm32::rcc::*;
        config.rcc.hsi = Some(HSIPrescaler::DIV1);
        config.rcc.csi = true;
        config.rcc.hsi48 = Some(Hsi48Config { sync_from_usb: true });
        config.rcc.pll1 = Some(Pll {
            source: PllSource::HSI,
            prediv: PllPreDiv::DIV4,
            mul: PllMul::MUL50,
            divp: Some(PllDiv::DIV2),
            divq: None,
            divr: None,
        });
        config.rcc.sys = Sysclk::PLL1_P;
        config.rcc.ahb_pre = AHBPrescaler::DIV2;
        config.rcc.apb1_pre = APBPrescaler::DIV2;
        config.rcc.apb2_pre = APBPrescaler::DIV2;
        config.rcc.apb3_pre = APBPrescaler::DIV2;
        config.rcc.apb4_pre = APBPrescaler::DIV2;
        config.rcc.voltage_scale = VoltageScale::Scale1;
        config.rcc.mux.usbsel = mux::Usbsel::HSI48;
    }
    let p = embassy_stm32::init(config);
    info!("STM32H723ZG-CoreBoard USB-CDC console");

    let mut led = Output::new(p.PB0, Level::Low, Speed::Low);

    let mut ep_out_buffer = [0u8; 256];
    let mut usb_config = embassy_stm32::usb::Config::default();
    usb_config.vbus_detection = false;

    let driver = Driver::new_fs(
        p.USB_OTG_HS,
        Irqs,
        p.PA12,
        p.PA11,
        &mut ep_out_buffer,
        usb_config,
    );

    let mut config = embassy_usb::Config::new(0xc0de, 0xcafe);
    config.manufacturer = Some("auto_probe");
    config.product = Some("H723 CoreBoard console");
    config.serial_number = Some("0001");

    let mut config_descriptor = [0; 256];
    let mut bos_descriptor = [0; 256];
    let mut control_buf = [0; 64];

    let mut state = State::new();

    let mut builder = Builder::new(
        driver,
        config,
        &mut config_descriptor,
        &mut bos_descriptor,
        &mut [],
        &mut control_buf,
    );

    let mut class = CdcAcmClass::new(&mut builder, &mut state, 64);

    let mut usb = builder.build();
    let usb_fut = usb.run();

    let console_fut = async {
        loop {
            class.wait_connection().await;
            info!("host connected");
            let _ = console(&mut class, &mut led).await;
            info!("host disconnected");
        }
    };

    join(usb_fut, console_fut).await;
}

struct Disconnected {}

impl From<EndpointError> for Disconnected {
    fn from(val: EndpointError) -> Self {
        match val {
            EndpointError::BufferOverflow => panic!("buffer overflow"),
            EndpointError::Disabled => Disconnected {},
        }
    }
}

async fn console<'d, T: Instance + 'd>(
    class: &mut CdcAcmClass<'d, Driver<'d, T>>,
    led: &mut Output<'_>,
) -> Result<(), Disconnected> {
    let mut buf = [0u8; 64];
    let mut line = [0u8; 64];
    let mut len = 0usize;

    class
        .write_packet(b"auto_probe H723 console. commands: on, off, status\r\n")
        .await?;

    loop {
        let n = class.read_packet(&mut buf).await?;
        for &b in &buf[..n] {
            match b {
                b'\r' | b'\n' => {
                    if len > 0 {
                        let reply = run_command(&line[..len], led);
                        class.write_packet(reply).await?;
                        len = 0;
                    }
                }
                _ if len < line.len() => {
                    line[len] = b;
                    len += 1;
                }
                _ => len = 0, // overflow: drop the line
            }
        }
    }
}

fn run_command<'a>(cmd: &[u8], led: &mut Output<'_>) -> &'a [u8] {
    match cmd {
        b"on" => {
            led.set_high();
            info!("cmd: on");
            b"OK: LED on\r\n"
        }
        b"off" => {
            led.set_low();
            info!("cmd: off");
            b"OK: LED off\r\n"
        }
        b"status" => {
            if led.is_set_high() {
                b"LED is on\r\n"
            } else {
                b"LED is off\r\n"
            }
        }
        _ => b"ERR: unknown command (on, off, status)\r\n",
    }
}

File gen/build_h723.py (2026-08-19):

#!/usr/bin/env python3
"""Генератор проекта KiCad: STM32H723ZGT6 core board (LQFP144), 84x84 мм, 4 слоя."""
import os, sys, math, json, re
sys.path.insert(0, os.path.dirname(os.path.abspath(__file__)))
import kicadenv
import pcbnew
import pcbhelp
from pcbhelp import Builder, mm, tomm, FPDIR
import kigen

OUT = sys.argv[1] if len(sys.argv) > 1 else "/home/claude/stm32boards/out/STM32H723ZG-CoreBoard"
NAME = "STM32H723ZG-CoreBoard"
CX, CY = 150.0, 100.0
BW = BH = 84.0
OFFX = 6.0                                 # кристалл левее центра платы
OFFY = 6.0                                 # кристалл выше нижнего края: кольца сверху и
BCX, BCY = CX + OFFX, CY - OFFY            # справа шире - там разъёмы, кнопки и брендинг
# Внутренний ряд гребёнки - ровно 11 x 2.54 от центра: противоположные гребёнки
# оказываются на шаге 22 x 2.54 и плата садится в макетку. Заодно это тот минимум,
# при котором веер из 36 выводов на сторону успевает разойтись с зазором 0.2 мм:
# крайние дорожки идут под 42 градуса, поперёк соседа остаётся 0.5*cos42 = 0.37 мм.
HDI, HDO = 27.94, 30.48                    # внутренний / внешний ряд гребёнки
APPR = 1.5                                 # где диагональ веера упирается в ряд гребёнки
X0, X1, Y0, Y1 = BCX - BW / 2, BCX + BW / 2, BCY - BH / 2, BCY + BH / 2
FCU, BCU = pcbnew.F_Cu, pcbnew.B_Cu
W, WP, WD = 0.15, 0.35, 0.15               # сигнальная / силовая / USB D+D-

MCU_LIBID = "MCU_ST_STM32H7:STM32H723ZGTx"
MCU_FP = ("Package_QFP", "LQFP-144_20x20mm_P0.5mm")
SPECIAL = {105: "SWDIO", 109: "SWCLK", 103: "USB_DM", 104: "USB_DP",
           8: "LSE_IN", 9: "LSE_OUT", 23: "HSE_IN", 24: "HSE_OUT",
           46: "LED_A", 71: "VCAP1", 106: "VCAP2"}
NO_HEADER = {8, 9, 23, 24, 71, 106}
PWRNET = {"VDD": "+3V3", "VSS": "GND", "VBAT": "+3V3", "VDDA": "+3V3A",
          "VSSA": "GND", "VREF+": "+3V3A", "VDD33USB": "+3V3", "PDR_ON": "+3V3"}

sym = kigen.get_symbol(MCU_LIBID)
PINNAME = {int(p.number): re.split(r"[(/]", p.name)[0] for p in sym.pins}
RAWNAME = {int(p.number): p.name for p in sym.pins}


def mcu_net(n):
    raw = RAWNAME[n]
    if raw in PWRNET:
        return PWRNET[raw]
    return SPECIAL.get(n, PINNAME[n])


C0402 = ("Capacitor_SMD", "C_0402_1005Metric")
C0603 = ("Capacitor_SMD", "C_0603_1608Metric")
C0805 = ("Capacitor_SMD", "C_0805_2012Metric")
R0402 = ("Resistor_SMD", "R_0402_1005Metric")
HDRLIB = "Connector_PinHeader_2.54mm"

b = Builder(layers=4)
u1 = b.place("U1", MCU_FP[0], MCU_FP[1], CX, CY, 0, value="STM32H723ZGT6")
pads = {int(p.GetNumber()): (tomm(p.GetPosition().x) - CX, tomm(p.GetPosition().y) - CY) for p in u1.Pads()}
sides = {"L": [], "B": [], "R": [], "T": []}
for n, (x, y) in pads.items():
    sides["L" if x < -10 else "R" if x > 10 else "T" if y < -10 else "B"].append(n)
for k in ("L", "R"):
    sides[k].sort(key=lambda n: pads[n][1])
for k in ("T", "B"):
    sides[k].sort(key=lambda n: pads[n][0])
assert all(len(v) == 36 for v in sides.values()), {k: len(v) for k, v in sides.items()}

# Выводы для разъёма прошивки. SWO у H7 только на PB3, а UART берём USART3 (PC10/PC11):
# эта пара выходит на верхнюю гребёнку рядом со SWCLK, тогда как USART1 (PA9/PA10)
# лежит на правой гребёнке за коридором USB, куда дорожку уже не провести.
pin_of = lambda nm: next(n for n in pads if PINNAME[n] == nm)
UTX, URX, SWO = pin_of("PC10"), pin_of("PC11"), pin_of("PB3")

# ---------------------------------------------------------- гребёнки 2x18
HL = 17 * 2.54
b.place("J2", HDRLIB, "PinHeader_2x18_P2.54mm_Vertical", CX - HDO, CY - HL / 2, 0, value="PORT_L")
b.place("J4", HDRLIB, "PinHeader_2x18_P2.54mm_Vertical", CX + HDI, CY - HL / 2, 0, value="PORT_R")
b.place("J5", HDRLIB, "PinHeader_2x18_P2.54mm_Vertical", CX - HL / 2, CY - HDI, 90, value="PORT_T")
b.place("J3", HDRLIB, "PinHeader_2x18_P2.54mm_Vertical", CX - HL / 2, CY + HDO, 90, value="PORT_B")
HSIDE = {"L": "J2", "B": "J3", "R": "J4", "T": "J5"}
SD = {"L": (-1, 0), "R": (1, 0), "T": (0, -1), "B": (0, 1)}

hdrmap, hdrof = {}, {}
for s_, ref in HSIDE.items():
    sx, sy = SD[s_]
    hp = [(int(p.GetNumber()), tomm(p.GetPosition().x), tomm(p.GetPosition().y)) for p in b.fps[ref].Pads()]
    tr = (lambda t: t[1]) if sx else (lambda t: t[2])      # поперёк платы
    al = (lambda t: t[2]) if sx else (lambda t: t[1])      # вдоль гребёнки
    vals = sorted({round(tr(t), 2) for t in hp})
    inner_v = vals[-1] if (sx < 0 or sy < 0) else vals[0]  # ближний к центру ряд
    inner = sorted([t for t in hp if abs(tr(t) - inner_v) < 0.1], key=al)
    outer = sorted([t for t in hp if abs(tr(t) - inner_v) >= 0.1], key=al)
    for i, mn in enumerate(sides[s_]):
        j, row = i // 2, i % 2
        hn, hx, hy = (inner if row == 0 else outer)[j]
        gap = al(inner[j]) + 1.27                          # проход между падами внутреннего ряда
        hdrmap[(ref, hn)] = mn
        hdrof[mn] = dict(ref=ref, pin=hn, x=hx, y=hy, side=s_, row=row, col=j,
                         inner=(inner[j][1], inner[j][2]), gap=gap)

# ---------------------------------------------------------------- периферия
UCY = (hdrof[103]["y"] + hdrof[104]["y"]) / 2 + 16.0
b.place("J1", "Connector_USB", "USB_C_Receptacle_HRO_TYPE-C-31-M-12", X1 - 6.0, UCY, 90, value="USB-C")
# Разъём должен стоять на плате целиком, а не свисать за край. Двигаем его так,
# чтобы корпус кончался ровно на контуре: глубже нельзя - в край упрётся литьё
# вилки и она не сядет до конца.
_cb = b.fps["J1"].GetCourtyard(pcbnew.F_CrtYd).BBox()
b.fps["J1"].SetPosition(pcbnew.VECTOR2I(
    mm(tomm(b.fps["J1"].GetPosition().x) + (X1 - 0.05) - tomm(_cb.GetRight())), mm(UCY)))
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

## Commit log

2026-08-17 Добавить core-платы STM32G474 / STM32H723 и генератор
    Схема, размещение, разводка и шелкография описаны скриптами поверх
    pcbnew API, готовые файлы KiCad и гербера лежат в boards/.
    - boards/STM32G474RE-CoreBoard - 70x70 мм, 4 слоя, LQFP64, готова к заказу
    - boards/STM32H723ZG-CoreBoard - 84x84 мм, 4 слоя, LQFP144, черновик
    - gen/ - генератор и проверки (зазоры, связность, courtyard, шелкография)
    - docs/ - обзор открытых референсов ST и что из них применимо
    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
    [BOM.csv, PINOUT.csv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]
2026-08-17 Устранить замечания DRC KiCad на плате G474
    - Правило зазора в проекте приведено к 0.15 мм: плата разводилась под
    него, а KiCad ставил по умолчанию 0.2 и помечал 23 нормальных места
    как ошибки. Предел JLCPCB для этого процесса - 0.09 мм.
    - via VBAT (вывод 1) уехала на 0.137 мм от via GND вывода 63:
    укорочен отвод с 1.8 до 1.35 мм.
    - via USB_DM были 0.40/0.20 мм - ниже собственных правил платы,
    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
    [STM32G474RE-CoreBoard-B_Cu.gbl, STM32G474RE-CoreBoard-B_Mask.gbs, STM32G474RE-CoreBoard-B_Paste.gbp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]
2026-08-17 Довести G474 до чистого DRC KiCad при штатных 0.2 мм
    Раньше плата разводилась под 0.15 мм и правило проекта подгонялось под
    геометрию. Теперь наоборот - геометрия приведена к стандартным 0.2 мм,
    правило вернулось к значению по умолчанию.
    - сигнальные дорожки 0.2 -> 0.15 мм: при шаге выводов LQFP64 0.5 мм
    ширина 0.2 не оставляла 0.2 мм зазора в расходящемся веере
    - USB D+/D- 0.18 -> 0.14 мм: via D+ проходила в 0.185 мм от д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
    [BOM.csv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]
2026-08-17 Вернуть USB D+/D- к минимальной ширине 0.15 мм
    Прошлая правка увела пару на 0.14 мм - ниже собственного правила платы,
    KiCad выдал 11 ошибок track_width. Зазор добран не шириной дорожки, а
    уменьшенными via 0.4/0.2 мм на выходе из USB-C: при шаге падов 0.5 мм
    сумма 0.45/2 + 0.2 + 0.15/2 даёт ровно 0.5 - геометрия сходится впритык,
    без запаса. С via 0.4 зазор 0.225 мм.
    Минимум via по правилам платы снижен до 0.4/0.2 мм (предел JLCPCB -
    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
    [STM32G474RE-CoreBoard-B_Cu.gbl, STM32G474RE-CoreBoard-B_Mask.gbs, STM32G474RE-CoreBoard-B_Paste.gbp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]
2026-08-17 Уложить USB-пару в штатные правила без их изменения
    Прошлая правка снижала минимум via до 0.4/0.2 через .kicad_pro, но KiCad
    пользователя держит свою копию правил проекта и её не подхватывает.
    Поэтому плата приведена к правилам как есть: via 0.45/0.25, дорожка 0.15,
    зазор 0.2. На шаге падов USB-C 0.5 мм это даёт ровно 200000 нм - впритык,
    но проходит: KiCad считает нарушением строгое "меньше нормы".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
    [STM32G474RE-CoreBoard-B_Cu.gbl, STM32G474RE-CoreBoard-B_Mask.gbs, STM32G474RE-CoreBoard-B_Paste.gbp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]
2026-08-17 Перевести проект на собственную библиотеку футпринтов
    KiCad сверяет футпринты платы с библиотечными, а системные библиотеки
    меняются от версии к версии: KiCad 10 у пользователя давал 31
    предупреждение lib_footprint_mismatch против копий из KiCad 7.
    Генератор теперь выгружает все 14 использованных футпринтов в
    auto_probe.pretty рядом с платой и прописывает fp-lib-table. Плата и
    схема ссылаются на эту библиотеку. К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
    [BOM.csv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]
2026-08-18 Довести H723 до KiCad 10: разъём прошивки, STDC14, переразметка верхнего кольца
    Плата H723 пересобрана в формате KiCad 10 и подтянута к раскладке G474.
    Плата:
    - разъём прошивки J6 - 1x10 с распиновкой WeAct, развёрнут 5V к востоку,
    SWO садится на PB3 прямой дорожкой;
    - добавлен J7 - STDC14 (2x7, 1.27 мм), штатный разъём ST-LINK V3. Стоит
    вертикально сигнальным рядом к J6: строки веера идут по строкам падов и
    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
    [BOM.csv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]
2026-08-18 H723: убрать STDC14, переразметить верхнее кольцо и шелкографию под нормы печати
    Разъём прошивки и его окружение:
    - STDC14 (J7) снят с платы, из схемы и из библиотеки проекта: вертикально он
    занимал 7.6 мм по высоте и не давал поднять J6;
    - J6 поднят к верхнему краю (Y0+5.2), обозначение закреплено в торце справа;
    - полосы SWO/CLK/DIO отведены от контура: было 0.67 мм до фрезы, стало 1.67;
    - BOOT0 к гребёнке обходит J6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
    [BOM.csv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]
2026-08-19 H723: кварц под наличие JLCPCB, номера LCSC в BOM, выходные файлы в их формате
    Кварц HSE переведён на корпус, который у JLCPCB есть как Basic Part:
    - Y1 - SMD-3225 с четырьмя падами (Yangxing X322525MOB4SI, C9006) вместо
    двухпадового 5032: тот только Extended и с перебоями в наличии;
    - сигнальные пады у 3225 стоят по диагонали, между ними земляные, поэтому оба
    сигнала заходят с запада разными колонками, а отвод HSE_OUT к своей банке
    и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
    [BOM.csv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]
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2026-10-07 G474: подготовка к заказу JLCPCB - кварцы под склад, легенда на шелкографии
    Кварцы подобраны по наличию: HSE 8 МГц X50328MSB2GI (C115962, Basic, CL 20 пФ)
    с обвязкой 33 пФ (C1562, Basic) вместо 12 пФ; LSE остался C97606 (CL 12.5 пФ),
    обвязка 6.8 пФ -> 18 пФ как на H723. Номиналы исправлены в схеме, плате и на
    шелкографии, цепи не менялись.
    Шелкография: номиналы у деталей заменены легендой на нижней стороне (стиль
    H723, компактнее), у ком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
    [BOM.csv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]
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2026-10-12 Voice-Unit: голосовой модуль на ESP32-S3, 2x I2S-микрофона + усилитель 3 Вт
    ESP32-S3-WROOM-1-N16R8, два ICS-43434 (общая I2S-шина, LR: MK1 левый, MK2 правый),
    MAX98357A на выносной динамик, стабилизатор TLV75733 (C5 1 мкФ на выходе по даташиту),
    питание USB-C или JST PH 4p "5V IN" через диодное ИЛИ SS34, UART к мозгам на J4,
    крепёж 4x M2.5. Распиновка микрофонов исправлена по даташиту DS-000069 (табл. 8).
    Заказ 5 шт. Standard PCBA в корзине JLCPCB, не оплачен.
    Battery-Unit: з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
